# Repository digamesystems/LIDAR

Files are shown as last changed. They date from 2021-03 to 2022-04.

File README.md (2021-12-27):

## Title: 
Next-Generation systems for Park Data collection

### Authors: 
John Price, Jason Pitts, Bailee Allen, Jared Plunket

### Abstract: 

Recent advances in low power wireless technologies have enabled simple, high-speed connectivity to sensors used for gathering environmental data. Much of the currently deployed sensor infrastructure in the park system, however, is not designed to support wireless connectivity. As a result, park staff are required to visit each sensor site and make manual connections to devices to download data for applications like trail use monitoring. Sometimes these sensors are in areas with rugged terrain, adding to the difficulty in extracting the information and even increasing risk to the safety of park personelle. We propose to explore adding a low-power wireless link, (Bluetooth Low Energy, WiFi and LoRAWAN) to novel environmental sensors to allow ‘touchless’ access to this information. 

### Technical Approach: 
The need for accurate statistics around the use of our recreation areas has been well appreciated for some time:

“Every manager of a recreation site needs three essential statistics: man-hours of use, number of visits, and peak loads.” (James and Ripley,1963) [[1](https://github.com/digamesystems/LIDAR/blob/main/docs/Reference/rp_se003.pdf)]

In trail utilization applications, these statistics are often gathered by infrared detectors tied to a microprocessor-controlled counter with memory that logs the data as a function of time. One popular system of this type is made by TRAFX Research Ltd. [[2](https://www.trafx.net/about)]. We propose to add a combination of WiFi, Bluetooth and LoRaWAN connectivity to the system to enable ‘touchless’ downloading of information from the device’s memory when a researcher is near. 
 
Other applications include Vehicle Counting to better understand Park Visitation statistics.

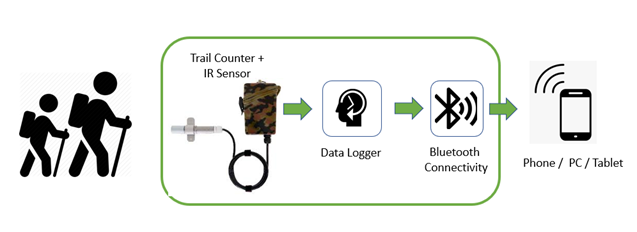
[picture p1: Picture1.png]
System Schematic


*Figure 1.* Proposed System

A working prototype will be developed to allow the exploration of: 
- Power and cost limitations for a next generation system
- Wireless performance under various conditions including range, connection speed and reliability
- New sensor technologies like LIDAR that might eliminate the drawbacks of current "On Road" sensor solutions
- Environmental requirements 
- User experience and UI design 
- Impact of ‘touchless’ downloads on system reliability
- How this capability might improve the quality of research data.
  
The project would also serve as a learning platform for the student intern community, offering opportunities in electrical, mechanical and software engineering.

### References: 
[[1](https://github.com/digamesystems/LIDAR/blob/main/docs/Reference/rp_se003.pdf)] - Instructions for Using Traffic Counters to Estimate Recreation Visits and Use George A. James; Thomas H. Ripley, Res. Pap. SE-3. Asheville, NC: U.S. Department of Agriculture, Forest Service, Southeastern Forest Experiment Station. 14 p. (1963).

[[2](https://www.trafx.net/about)] – TRAFX Research Ltd.

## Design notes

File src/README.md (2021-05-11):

## Title: 
Source files for Next-Generation Systems for Park Data collection

### Authors: 
John Price

### Abstract: 

Found herein are source files for the project, including the main application(s), and example programs that demonstrate how to work with the various sensors / modules we are using. 

* [SerialToSerialBT](https://github.com/digamesystems/LIDAR/tree/main/src/SerialToSerialBT) This example code is in the Public Domain (or CC0 licensed, at your option.) By Evandro Copercini - 2018. This example creates a bridge between Serial and Classical Bluetooth (SPP) and also demonstrate that SerialBT have the same functionalities of a normal Serial
* [esp32_bluetooth_tester](https://github.com/digamesystems/LIDAR/tree/main/src/esp32_bluetooth_tester) A little app to test Bluetooth connectivity range. Make a Bluetooth connection to the device "ShuttleCounter" with [Serial BlueTooth Terminal](https://play.google.com/store/apps/details?id=de.kai_morich.serial_bluetooth_terminal&hl=en_US&gl=US). The device will issue a count value every second. 
* [esp32_people_counter](https://github.com/digamesystems/LIDAR/tree/main/src/esp32_people_counter) A LIDAR-Based people counting system for shuttle buses.
* [esp32_tfminiplus_correlation_test](https://github.com/digamesystems/LIDAR/tree/main/src/esp32_tfminiplus_correlation_test) Testing algorithms that use correlation techniques for Vehicle Detection.
* [esp32_tfminiplus_example](https://github.com/digamesystems/LIDAR/tree/main/src/esp32_tfminiplus_example) A little program to show how to work with the TFMini-Plus LIDAR sensor.
* [esp32_ttminiplus_sd_ds3231](https://github.com/digamesystems/LIDAR/tree/main/src/esp32_ttminiplus_sd_ds3231) The HEIMDALL vehicle counting application.

`

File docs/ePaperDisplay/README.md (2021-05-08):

# ePaper Display Candidates

WaveShare 
* [1.54 Inch ePaper Display](https://www.waveshare.com/product/displays/e-paper/1.54inch-e-paper-module.htm)

Adafruit
* [1.54 Inch ePaper Display + SD Card](https://www.adafruit.com/product/4196)
* [Technical Details](https://learn.adafruit.com/adafruit-1-54-eink-display-breakouts)
* [Arduino Library](https://github.com/adafruit/Adafruit_EPD)

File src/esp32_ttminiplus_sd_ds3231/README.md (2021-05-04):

## esp32_tfminiplus_sd_ds3231.ino

### Description:
This application supports the Digame Systems HEIMDALL traffic counting system. 

### Authors: 
John Price

### System Components:
* [ESP32 WROOM 32D development board](https://docs.espressif.com/projects/esp-idf/en/latest/esp32/hw-reference/esp32/get-started-devkitc.html)
* One of several compatible LIDAR sensors (see below)
* A [micro SD card breakout module](https://www.adafruit.com/product/254) for system configuration settings and backup.
* A battery backed [real time clock module](https://www.adafruit.com/product/3013)
* [Solar panel](https://voltaicsystems.com/9-watt-panel/)
* Rechargable [battery pack](https://voltaicsystems.com/v50/)
* IP67 Rated Enclosure

### Overview:

At startup, program parameters are read from a configuration file, CONFIG.TXT found on the micro SD card. These may be changed by editing the file. File format is simple text contiaining the following parameters: 

    device name  -- User Defined
    distance threshold -- Less than this distance detected by the LIDAR sensor counts as vehicle 'presence' 
    operating mode (currently only opmodeThreshold and opmodeCorrelation are supported)
    SSID -- Network name
    password -- Network password
    serverURL -- Address for http POSTs of JSON messages

Once parameters are loaded, the device attempts to connect to the network with the specified credentials. If successful, system time is set from a connection to an NTP server and the real time clock is updated. In the event of a failure, the last known time set in the RTC will be used. The RTC is based on the DS3231 chip which has high accuracy and is temperature compensated. It should be accurate to within a few seconds a year without adjustment.

At this point, the main loop executes and the system makes repeated distance measurments using the LIDAR sensor over UART. Default acquisition rate is 100Hz and the distances measured are accurate to a few centimeters over ranges from 0.1 - 12 meters (under optimal conditions).

The software is compatible with several LIDAR sensors from the [Benewake](http://en.benewake.com/) "TF" family: 
* [TFMini-S](http://en.benewake.com/product/detail/5c345e26e5b3a844c472329c.html) 0-12 M Range
* [TFMini-Plus](http://en.benewake.com/product/detail/5c345cd0e5b3a844c472329b.html) 0-12 M Range, IP67
* [TF-Luna](http://en.benewake.com/product/detail/5e1c1fd04d839408076b6255.html) 0-8 M Range, Low Cost
* [TF-03](http://en.benewake.com/product/detail/5c345cc2e5b3a844c472329a.html) 0-180 M Range!, IP67

Passing vehicles generate a characteristic signature as they travel through the beam which is interpreted by the software. -- Several algorithms for detection are under evaluation including threshold-based and correlation-based approaches.

On the detection of a vehicle, a JSON message is created for delivery to the server URL specified in the configuration. JSON messages are of the following format: 

    "{"deviceName": "YourDeviceName",
      "deviceMAC":  "YourMACAddress",
      "timeStamp":" "YourRTCTime (UTC)",
      "eventType":  "<boot|heartbeat|vehicle>"
      }"
      
For "vehicle" events, an optional array of raw LIDAR data maybe included in the payload:
   
    <...pseudo code snippet...>
    
    jsonPayload = jsonPayload + "operatingMode": "<opmodeThreshold|opmodeCorrelation>,"
    jsonPayload = jsonPayload + "rawData": + "["
    using index_t = decltype(buffer)::index_t;
    for (index_t i = 0; i < buffer.size(); i++) {
        jsonPayload = jsonPayload + buffer[i]; 
        if (i<buffer.size()-1){ 
          jsonPayload = jsonPayload + ",";
        }
    }
    //Close out the message
    jsonPayload = jsonPayload + "]}";
          
This allows us to analyze the last second or so of raw data before the sensor claimed that a car had passed.

An attempt is then made to send the data to the server. If this fails, data is saved to the SD card until a successful connection can be reestablished. Reconnect attempts are made every 5 minutes by default. Once a successful connection has been made, the data saved locally is sent to the server and upon completion, the data stored on the SD card is deleted.

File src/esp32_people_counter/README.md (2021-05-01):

## esp32_people_counter

### Description: 

A LIDAR-based sensor system for detecting people boarding and unboarding shuttle buses. Events are reported via Bluetooth Classic to a networked tablet that relays the information to a server. 

### Authors: 
John Price, Bailee Allen, Jared Plunket

### System Components:
* [ESP32 WROOM 32D development board](https://docs.espressif.com/projects/esp-idf/en/latest/esp32/hw-reference/esp32/get-started-devkitc.html)
* One of several compatible LIDAR sensors (see below)
* [Enclosure](https://www.polycase.com/dc-45f)

### JSON Bluetooth Payload:

The Sensor reports 'people' events over Bluetooth in JSON format. Examples:`

    {"deviceName":"Bailee's Office","deviceMAC":"60:3a:6a:2a:3:a8","eventType":"person","count":"1"}
    {"deviceName":"Bailee's Office","deviceMAC":"60:3a:6a:2a:3:a8","eventType":"person","count":"2"}
    {"deviceName":"Bailee's Office","deviceMAC":"60:3a:6a:2a:3:a8","eventType":"person","count":"3"}
    {"deviceName":"Bailee's Office","deviceMAC":"60:3a:6a:2a:3:a8","eventType":"person","count":"4"}

### Sensors:
The software is compatible with several LIDAR sensors from the [Benewake](http://en.benewake.com/) "TF" family: 
* [TFMini-S](http://en.benewake.com/product/detail/5c345e26e5b3a844c472329c.html) 0-12 M Range
* [TFMini-Plus](http://en.benewake.com/product/detail/5c345cd0e5b3a844c472329b.html) 0-12 M Range, IP67
* [TF-Luna](http://en.benewake.com/product/detail/5e1c1fd04d839408076b6255.html) 0-8 M Range, Low Cost
* [TF-03](http://en.benewake.com/product/detail/5c345cc2e5b3a844c472329a.html) 0-180 M Range!, IP67

### Testing the Sensor: 
* https://youtu.be/LPxUawpHUEk
* https://youtu.be/7mM1T-jgChU
* https://youtu.be/dQw4w9WgXcQ

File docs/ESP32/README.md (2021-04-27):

https://github.com/espressif/esp-idf/blob/cf457d4/docs/en/hw-reference/esp32/get-started-devkitc.rst

Pinout Reference Guide:
https://randomnerdtutorials.com/esp32-pinout-reference-gpios/

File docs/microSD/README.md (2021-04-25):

Adafruit microSD card breakout module:

https://github.com/adafruit/MicroSD-breakout-board

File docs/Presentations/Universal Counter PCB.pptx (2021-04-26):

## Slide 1

Counter Board Concept

eInk Display*

UI

Indicators / LEDs *

ESP32-WROOM-32D Dev Board

Micro SD Card Breakout *

LoRaWAN *

Wireless

WiFi

Battery-Backed Real Time Clock *

Peripherals

TFMini-Plus LIDAR Sensor Connector x2

Bluetooth / BLE

Temperature / Humidity Sensor *

Power: 5-12VDC, USB, Solar Panel

*Optional

## Counter Board Concept

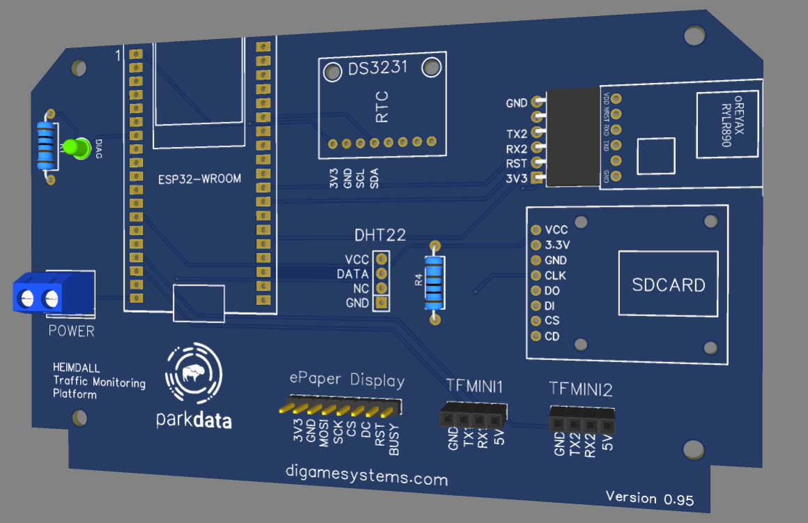
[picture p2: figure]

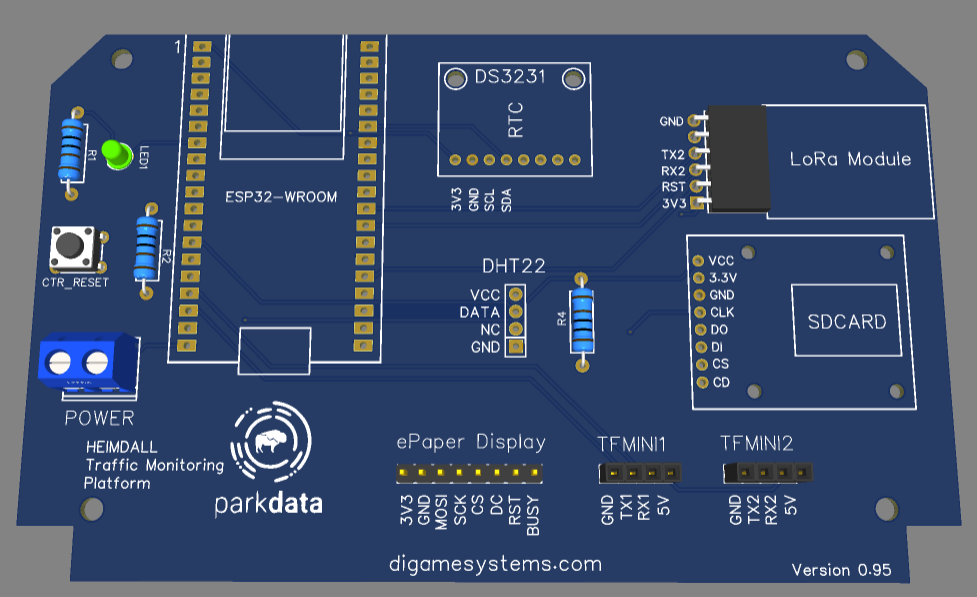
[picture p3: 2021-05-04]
images/Universal Counter PCB Concept/PCB_095_3D.png

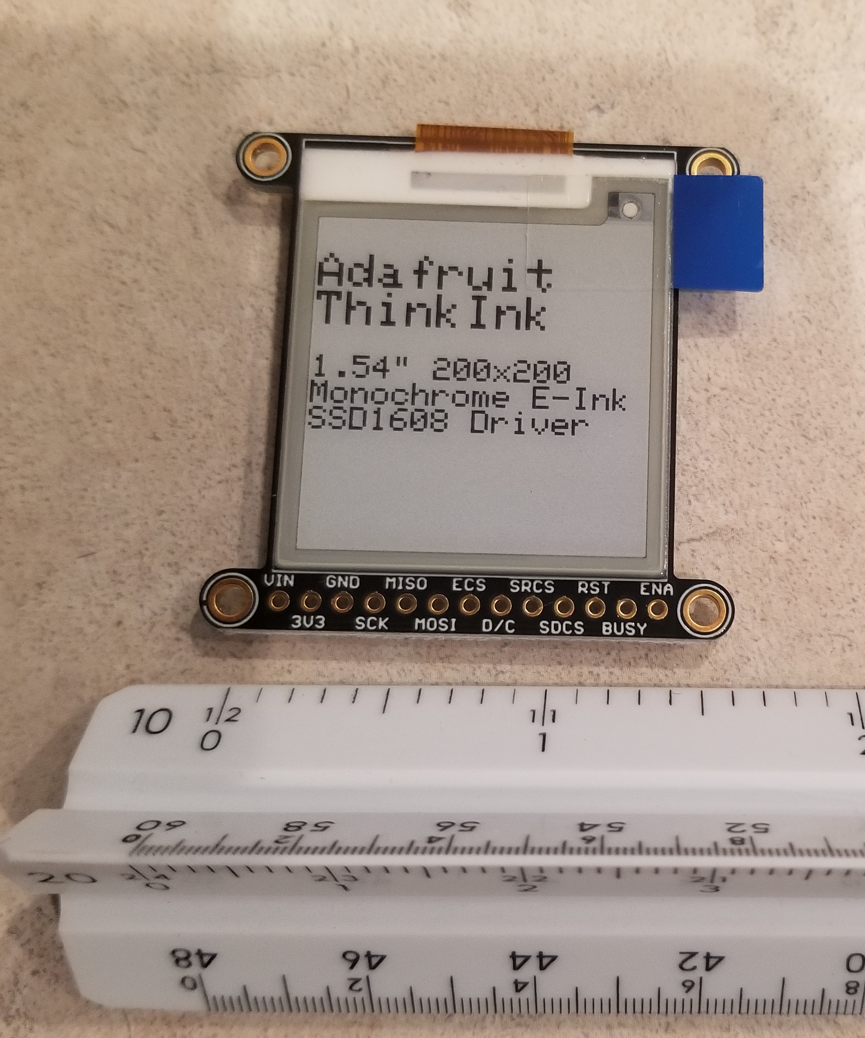
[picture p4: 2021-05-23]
docs/ePaperDisplay/Adafruit 1.54 inch ePape Display/adafruit1_54_eInk.jpg

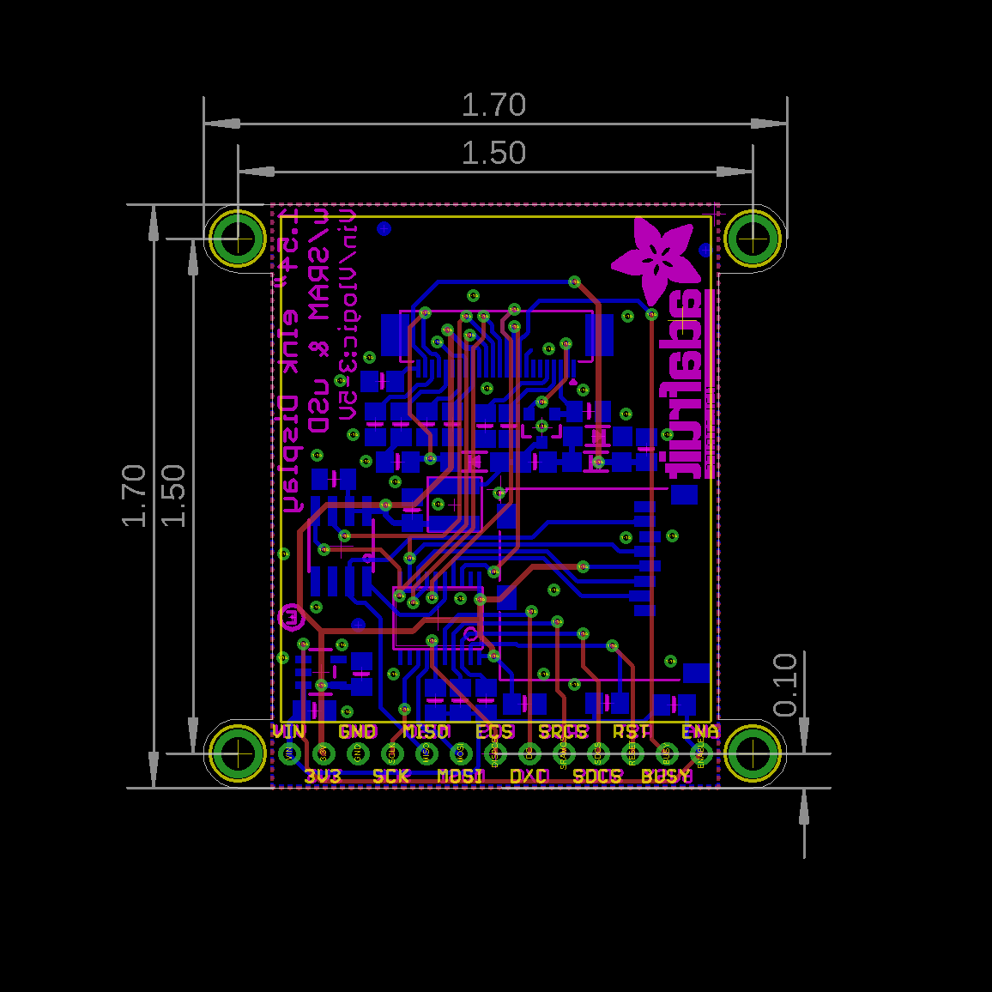
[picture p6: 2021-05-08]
docs/ePaperDisplay/WaveShare 1.54 inch ePaper Display/adafruit_1_54_e_ink_display.png

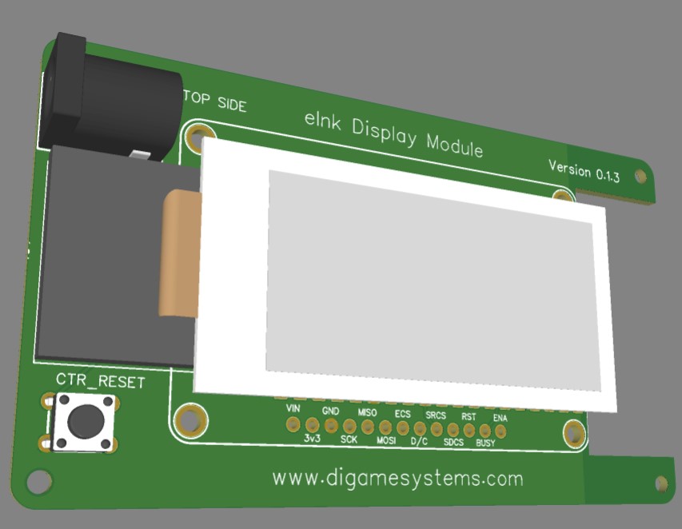
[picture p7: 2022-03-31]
images/Shuttle Counter Pics/Screenshot 2022-03-04 084442.jpg

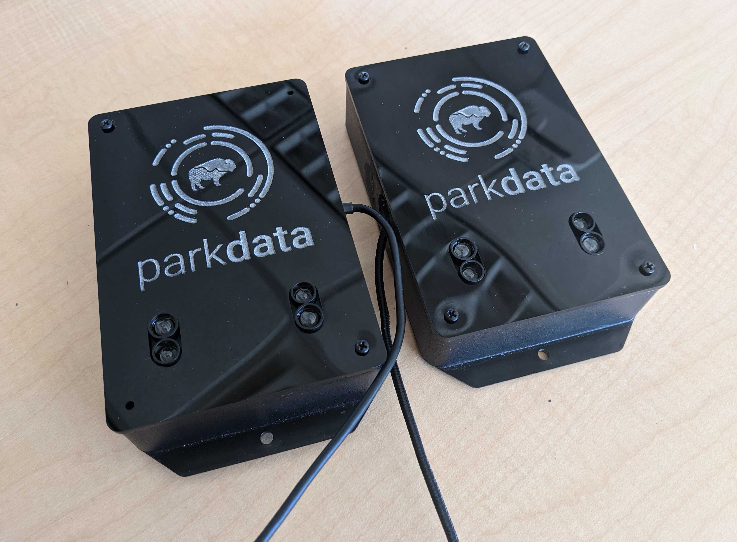
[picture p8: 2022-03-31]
images/Heimdall Pics/PXL_20211220_215736145.MP.jpg

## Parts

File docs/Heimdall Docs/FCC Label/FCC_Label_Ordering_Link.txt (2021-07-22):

https://www.onlinelabels.com/products/ol223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

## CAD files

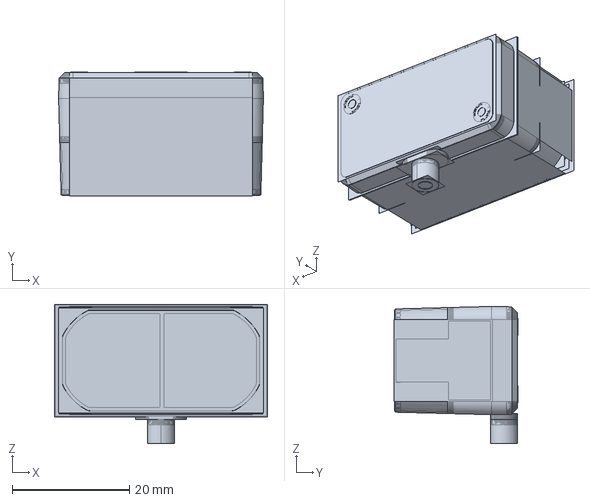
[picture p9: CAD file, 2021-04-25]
docs/LIDAR/TFMini-Plus/TFmini Plus 3D structure model.igs
36.4 x 21.2 x 23.8 mm

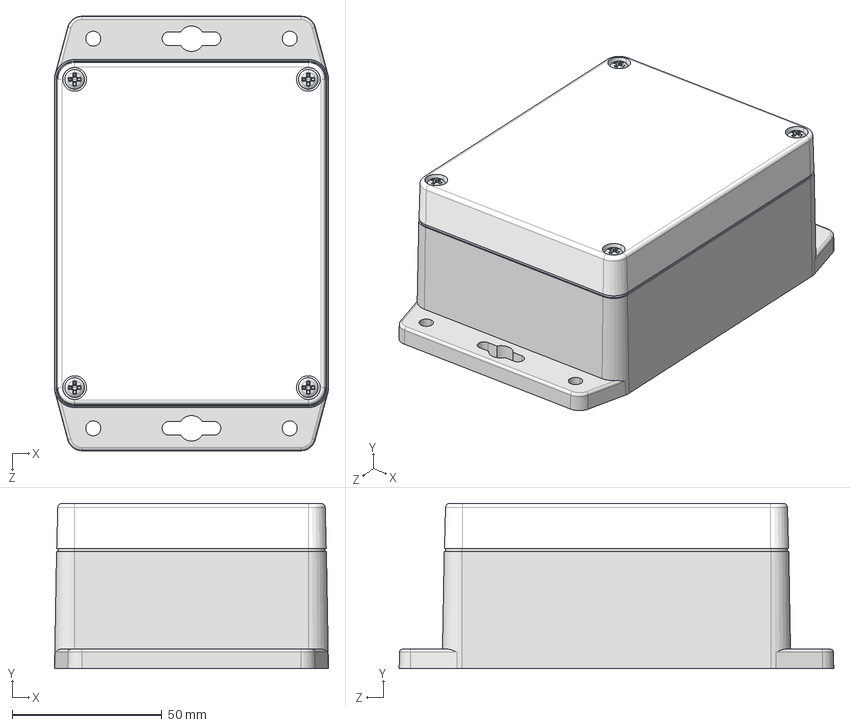
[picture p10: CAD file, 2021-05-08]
docs/Polycase/WC-23F/WC-23F.STEP
91.4 x 55.1 x 144.9 mm
W_-23BF_WP-23BF*15
W_-23C_WC-23C*08
SCREWS-SSM4-20_SCREWS-SSM4-20 x 4
W_-23BF-PCB_WP-23BF*15-PCB

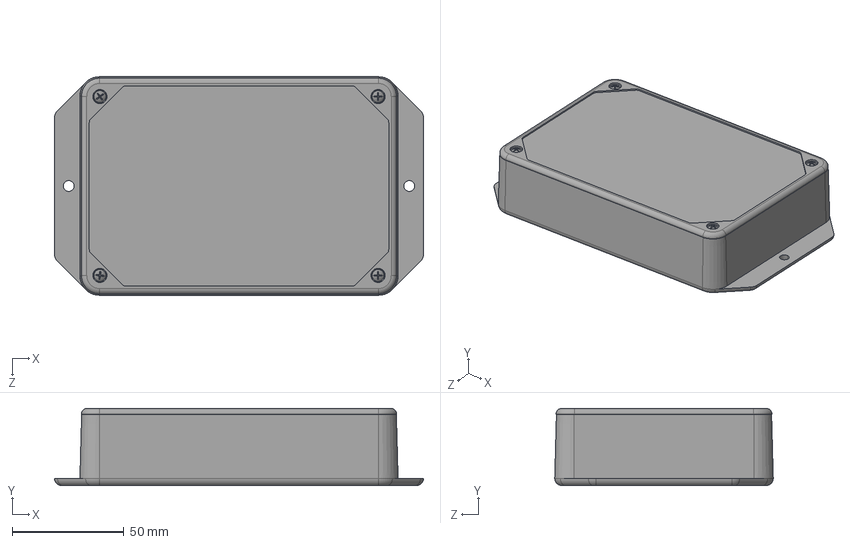
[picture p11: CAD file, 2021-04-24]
docs/Polycase/LP-61/LP-61FMBR_ASS'Y.STEP
165.1 x 34.5 x 97.8 mm
SCREWS-LP-BR_SCREWS-LP-BR x 4
LP-61B_LP-61BFMB
LP-61C_LP-61C-R

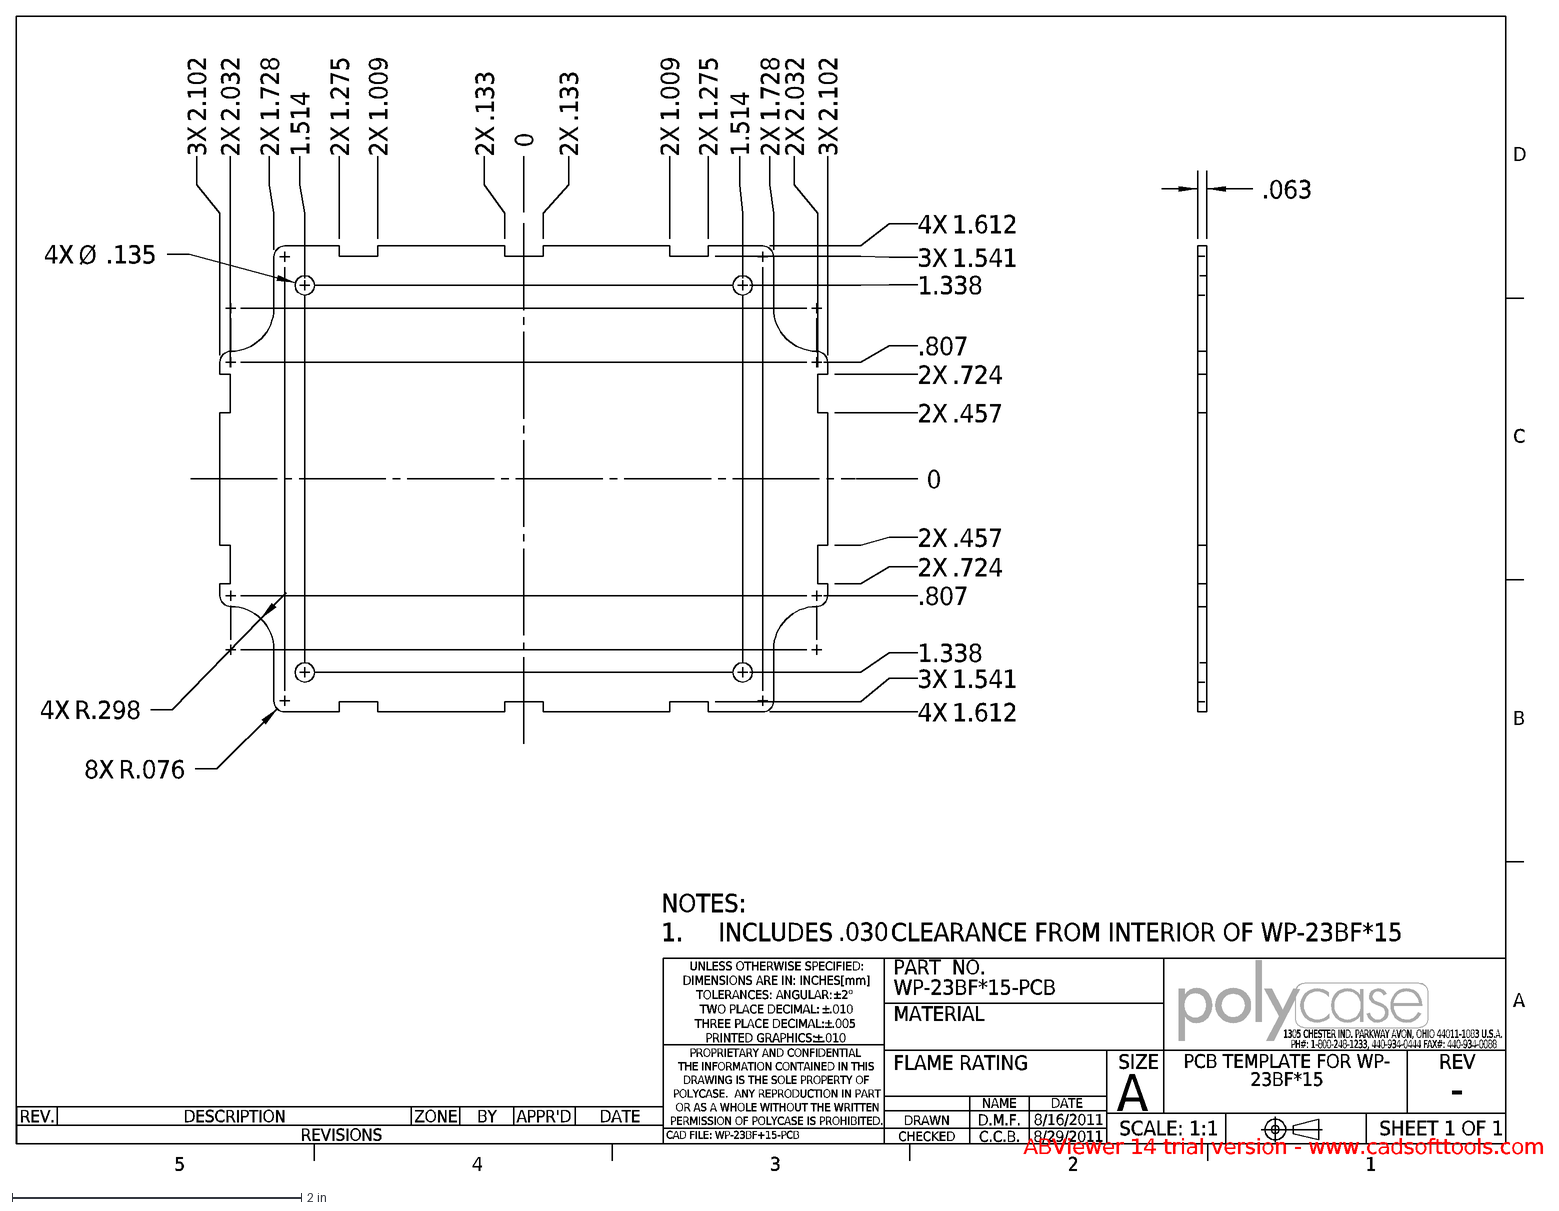
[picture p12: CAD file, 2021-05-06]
docs/Polycase/WC-23F/WP-23BF+15-PCB.dxf
1305 CHESTER IND. PARKWAY AVON, OHIO 44011-1083 U.S.A.
PH#: 1-800-248-1233, 440-934-0444 FAX#: 440-934-0088
NOTES:
INCLUDES
.030
CLEARANCE FROM INTERIOR OF WP-23BF*15
1.
1
A
B
C
D
2
3
4
5
SHEET 1 OF 1
SCALE: 1:1
REV
PART NO.
SIZE
PROPRIETARY AND CONFIDENTIAL
THE INFORMATION CONTAINED IN THIS
DRAWING IS THE SOLE PROPERTY OF
POLYCASE. ANY REPRODUCTION IN PART
OR AS A WHOLE WITHOUT THE WRITTEN
PERMISSION OF POLYCASE IS PROHIBITED.
PCB TEMPLATE FOR WP-
23BF*15
C.C.B.
D.M.F.
CHECKED
DRAWN
NAME
DATE
8/16/2011
8/29/2011
MATERIAL
FLAME RATING
-
CAD FILE: WP-23BF+15-PCB
UNLESS OTHERWISE SPECIFIED:
DIMENSIONS ARE IN: INCHES[mm]
TOLERANCES: ANGULAR:
±
°
TWO PLACE DECIMAL:
.010
THREE PLACE DECIMAL:
.005
PRINTED GRAPHICS:
WP-23BF*15-PCB
REV.
DESCRIPTION
ZONE
BY
APPR'D
REVISIONS
0
1.514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

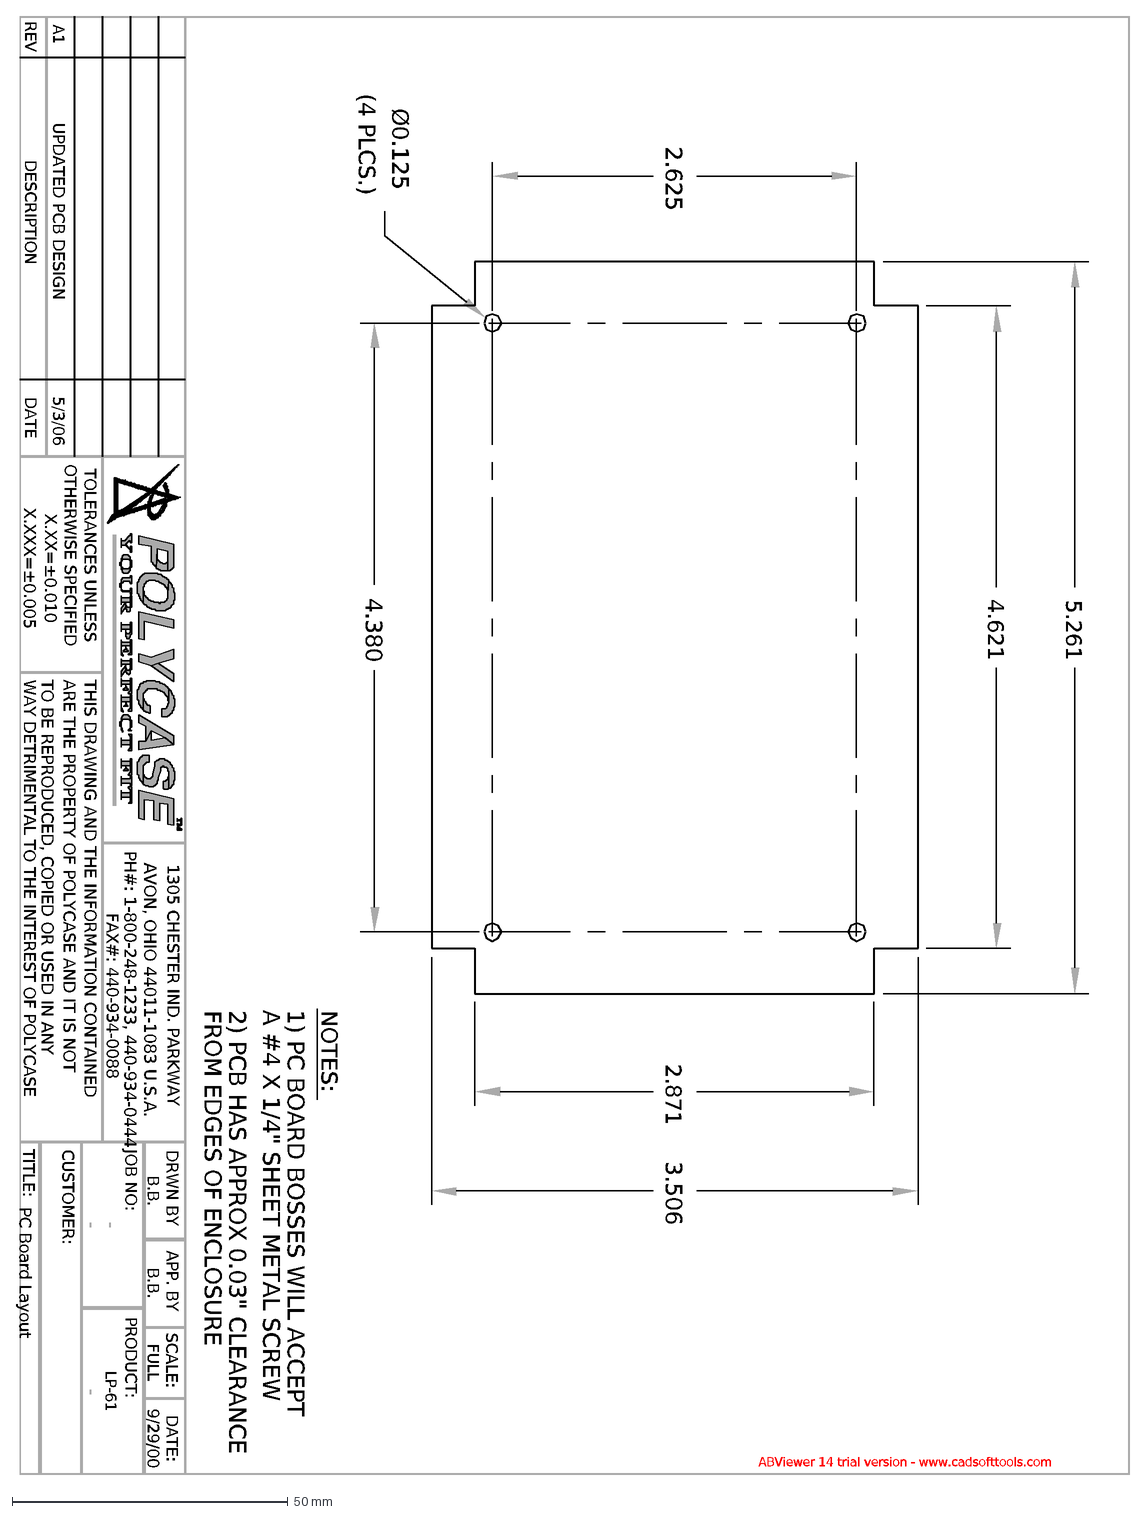
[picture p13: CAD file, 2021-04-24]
docs/Polycase/LP-61/PCB template PDF 7.dxf
REV
DESCRIPTION
DATE
OTHERWISE SPECIFIED
WAY DETRIMENTAL TO THE INTEREST OF POLYCASE
ARE THE PROPERTY OF POLYCASE AND IT IS NOT
THIS DRAWING AND THE INFORMATION CONTAINED
AVON, OHIO 44011-1083 U.S.A.
PH#: 1-800-248-1233, 440-934-0444
1305 CHESTER IND. PARKWAY
TO BE REPRODUCED, COPIED OR USED IN ANY
X.XXX=±0.005
TOLERANCES UNLESS
X.XX=±0.010
FAX#: 440-934-0088
DATE:
TITLE:
APP. BY
CUSTOMER:
JOB NO:
DRWN BY
PRODUCT:
SCALE:
B.B.
FULL
9/29/00
LP-61
PC Board Layout
NOTES:
1) PC BOARD BOSSES WILL ACCEPT
A #4 X 1/4" SHEET METAL SCREW
2) PCB HAS APPROX 0.03" CLEARANCE
FROM EDGES OF ENCLOSURE
2.871
3.506
4.621
5.261
2.625
4.380
Ø0.125
(4 PLCS.)
A1
UPDATED PCB DESIGN
5/3/06
ABViewer 14 trial version - www.cadsofttools.com

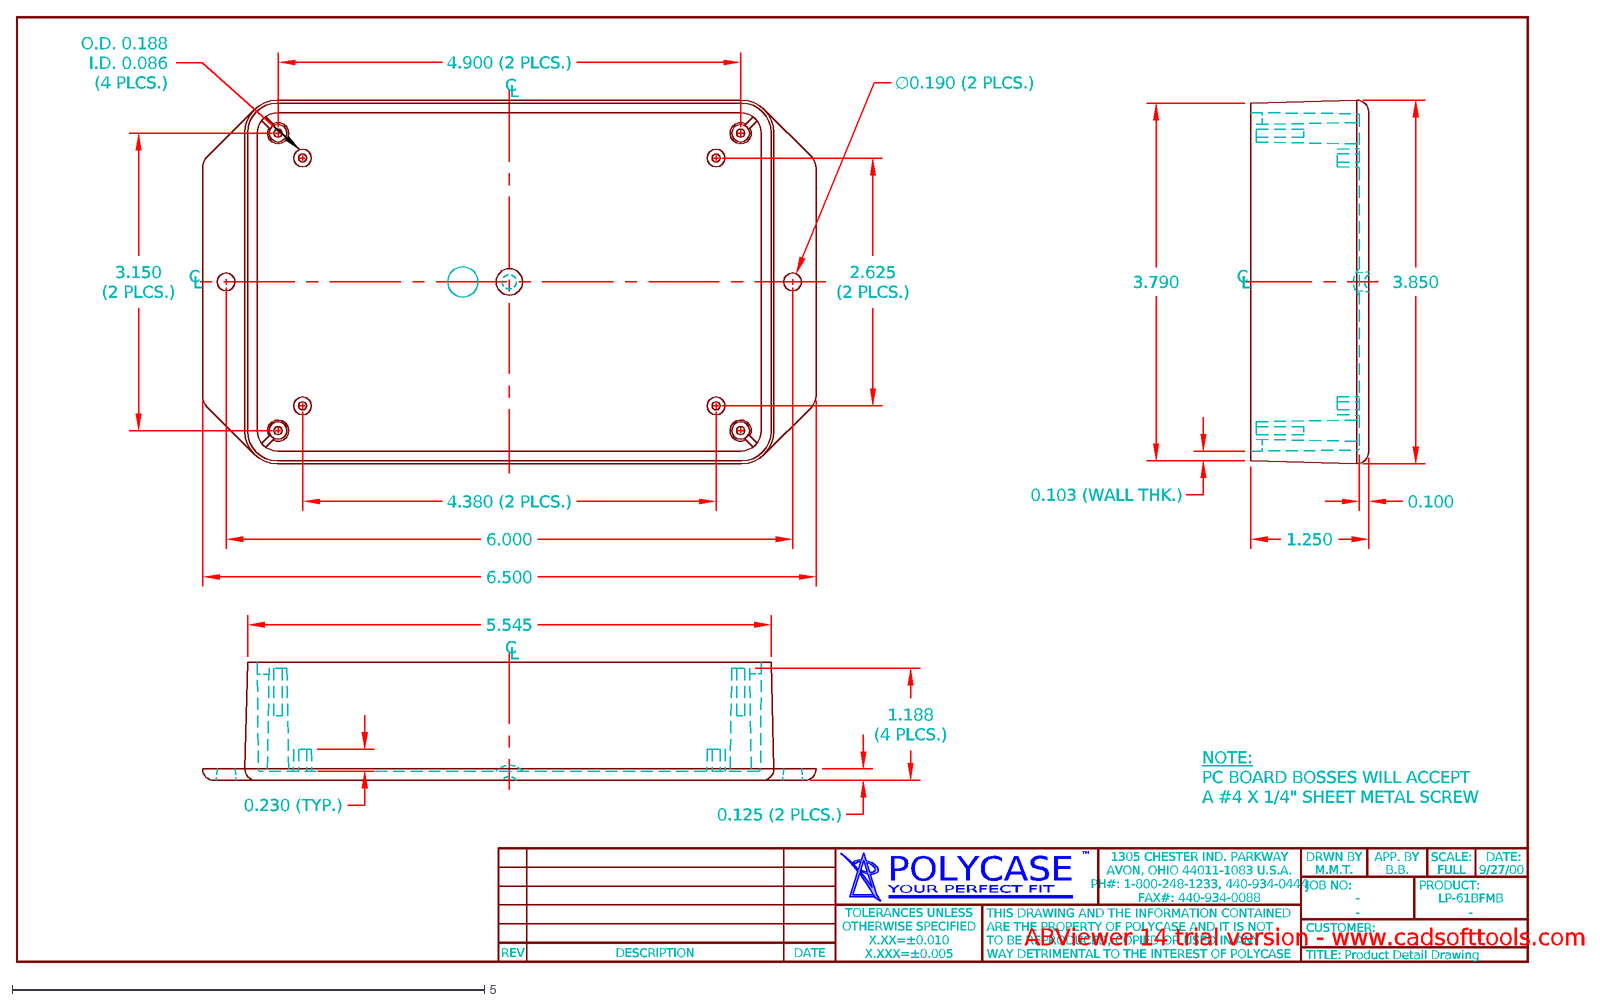
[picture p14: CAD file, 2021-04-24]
docs/Polycase/LP-61/LP-61BFMB.dxf
DESCRIPTION
REV
DATE
M.M.T.
B.B.
FULL
9/27/00
-
LP-61BFMB
Product Detail Drawing
POLYCASE
YOUR PERFECT FIT
TM
OTHERWISE SPECIFIED
WAY DETRIMENTAL TO THE INTEREST OF POLYCASE
ARE THE PROPERTY OF POLYCASE AND IT IS NOT
THIS DRAWING AND THE INFORMATION CONTAINED
AVON, OHIO 44011-1083 U.S.A.
PH#: 1-800-248-1233, 440-934-0444
1305 CHESTER IND. PARKWAY
TO BE REPRODUCED, COPIED OR USED IN ANY
X.XXX=±0.005
TOLERANCES UNLESS
X.XX=±0.010
FAX#: 440-934-0088
DATE:
TITLE:
APP. BY
CUSTOMER:
JOB NO:
DRWN BY
PRODUCT:
SCALE:
C
L
4.380 (2 PLCS.)
6.000
6.500
4.900 (2 PLCS.)
3.150 (2 PLCS.)
2.625 (2 PLCS.)
O.D. 0.188 I.D. 0.086 (4 PLCS.)
3.850
3.790
0.103 (WALL THK.)
0.100
1.250
5.545
0.230 (TYP.)
0.125 (2 PLCS.)
1.188 (4 PLCS.)
NOTE: PC BOARD BOSSES WILL ACCEPT A #4 X 1/4" SHEET METAL SCREW
∅0.190 (2 PLCS.)
ABViewer 14 trial version - www.cadsofttools.com

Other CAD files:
docs/Polycase/LP-61/LP-61PCB.dwg
docs/Polycase/WC-36/WP-36BF+15.DWG
docs/Polycase/WC-36/WC-36C+08.DWG
docs/Polycase/WC-23F/WP-23BF+15.DWG
docs/Polycase/WC-36/WP-36B+15-PCB.dxf
docs/Polycase/LP-61/LP-61C-R.dwg
docs/Polycase/WC-23F/WC-23F+1508.DWG
docs/Polycase/WC-36/WC-36F+1508.DWG
docs/Polycase/WC-23F/WC-23C+08.DWG
docs/Polycase/LP-61/LP-61FXXT_ASS'Y.STEP
docs/Polycase/LP-61/LP-61FXXR_ASS'Y.STEP
docs/Polycase/LP-61/LP-61FMBT_ASS'Y.STEP
docs/LIDAR/TFMini-Plus/tfmini_plus.blend
docs/Polycase/LP-61/LP-61BFMB.dwg
docs/Polycase/LP-61/LP-61C-T.dwg
docs/Polycase/WC-23F/WP-23BF+15-PCB.DWG
docs/Polycase/WC-36/WP-36B+15-PCB.DWG
docs/Solar Panel and Battery/solar panel and battery.blend
docs/ePaperDisplay/WaveShare 1.54 inch ePaper Display/1_54inch_display.blend
docs/microSD/Micro_SD_Breakout.blend

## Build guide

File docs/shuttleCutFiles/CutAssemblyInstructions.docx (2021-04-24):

Sensor Enclosure Cut Files

Shuttle LIDAR Sensor | AXIS Communications case

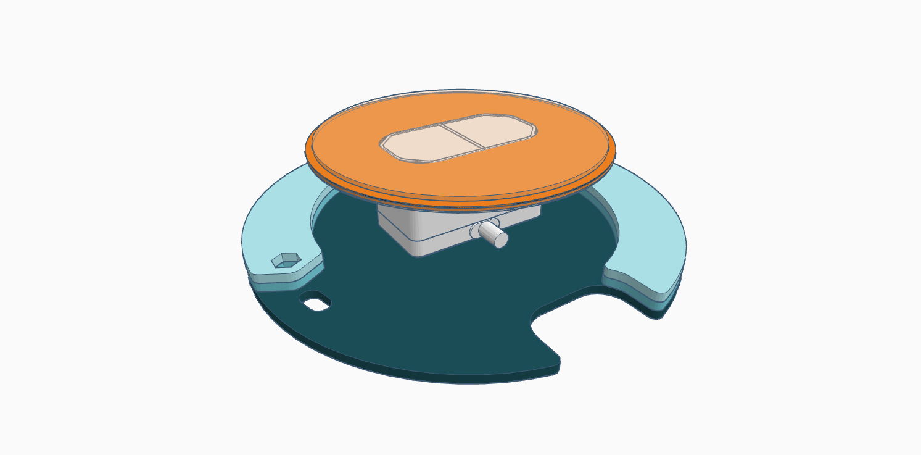
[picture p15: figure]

TO CUT:

Wood Base (Blue)

Material: ⅛ inch wood

Power Settings: Dependent on cutter

Files:

shuttleSensorBase.svg

shuttleSensorSpacers.svg

Acrylic Covers (Orange)

Material: 2mm Clear Acrylic

Power Settings: Dependent on cutter

Files:

shuttleSensorInnerCover.svg

shuttleSensorOuterCover.svg

Note:

Be sure to cover your acrylic with masking tape or use pre-masked acrylic sheeting to avoid scorch marks and heat patterns on the finished product.

TO ASSEMBLE:

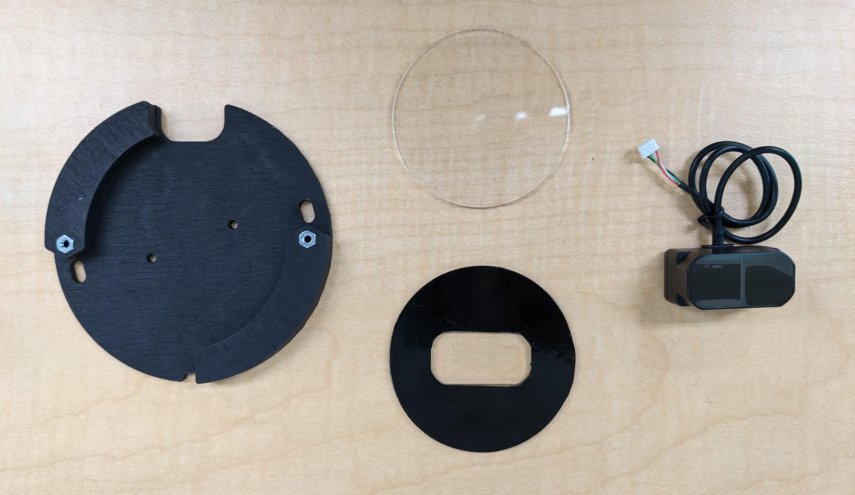
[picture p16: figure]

Materials:

Loctite or wood glue

M3-.50 Hex Nuts (2)

Black Vinyl Sticker

TF-Mini Plus LIDAR Sensor

Double Sided Sticky Tape

Instructions:

Cut black vinyl to fit inner acrylic piece and attach (shuttleSensorInnverCover.svg)

DO NOT LASER CUT VINYL.

Glue wood spacers together and attach to the wood base, lining up the perimeters as shown above.

Paint wood black if desired and insert hex nuts. Use tabletop or another solid surface to push them in until they are flush with the wood.

Insert clear acrylic cover into the top of the AXIS camera case and snap in black acrylic piece behind it to secure it.

Place the TF-mini plus sensor inside the indentation and screw the wooden base into place.

Note:

Use double sided sticky tape or other low-profile adhesive to keep the sensor in place if additional security is needed. Screwing into place is not necessary.

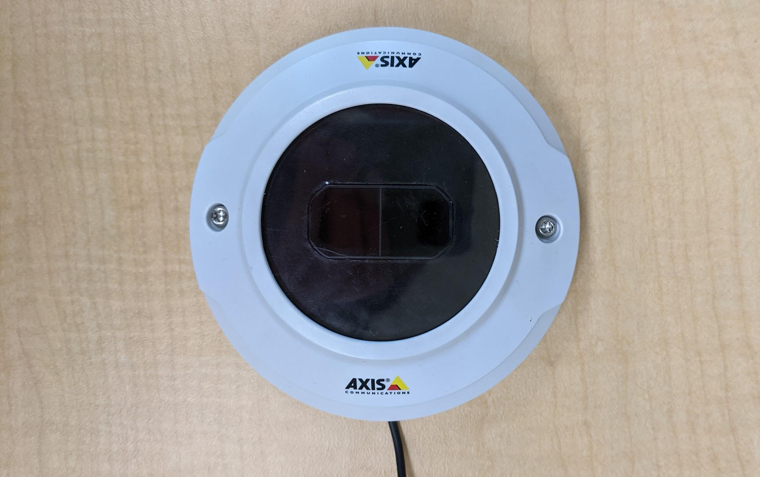
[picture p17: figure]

Finished product

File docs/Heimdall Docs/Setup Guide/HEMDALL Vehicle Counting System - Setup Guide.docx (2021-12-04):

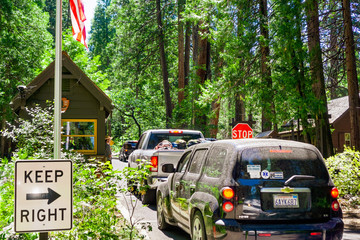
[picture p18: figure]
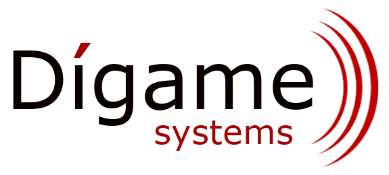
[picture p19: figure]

| HEMDALL VCS (Vehicle Counting System) Setup Guide Dígame Systems 88 E. San Fernando St. Suite 1511 San Jose, CA 95113

Trademarks

Dígame is a trademark of Dígame Sytems. Microsoft, Windows, and Windows NT are registered trademarks of Microsoft Corporation. Other brand and product names are registered trademarks or trademarks of their respective holders.

Statement of Conditions

In the interest of improving internal design, operational function, and/or reliability, Dígame reserves the right to make changes to the products described in this document without notice. Dígame does not assume any liability that may occur due to the use or application of the product(s) or circuit layout(s) described herein.

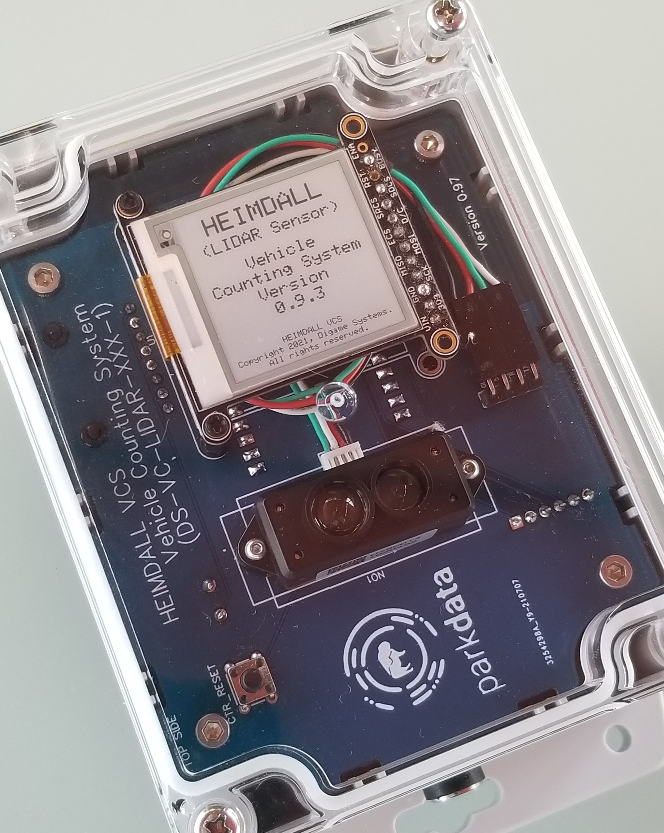
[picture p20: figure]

# Introduction

Thank you for your purchase!

The HEIMDALL VCS is an easy-to-deploy, state-of-the-art vehicle tracking system that provides fast, reliable traffic data for your application.

TODO: -- Put a blub here describing the collaboration between Dígame and the Parkdata project.

Unlike other vehicle counting technologies like loop sensors that require cutting up the roadway, HEIMDALL VCS is deployed roadside and never touches the road surface. This not only makes installation simple but saves on maintenance costs and reduces traffic disruptions.

The key is the sensing technology – LIDAR. The same technology used in some self-driving cars.

Vehicle counting sensors are deployed roadside and use an invisible laser to measure the distance from the sensor to any object in front of it up to 100 times per second. When a vehicle passes in front of the sensor, a characteristic “signature” is generated that the sensor uses to determine that a traffic event has occurred.

Vehicle events are transmitted wirelessly using a long-range RF link (LoRa) to a network base station that forwards the information to the Parkdata cloud service.

After a quick initial configuration, all of this happens automatically. Count events simply show up in the Parkdata dashboard.

Let’s get started.

# System Components

HEIMDAL VCS consists of several components that work together to feed data to the Parkdata system.

- A Solar Power System: Traffic Counters are powered by a rechargeable lithium-ion battery pack which is maintained by a 10 Watt solar panel. Both the panel and battery packs are weatherproof and designed to be mounted outdoors, near the sensor.
- One or more LIDAR Vehicle Counters: Vehicle counters are typically mounted on a post roadside pointing across traffic. The LIDAR sensor is placed at a height of about one meter above the road’s surface so the laser can easily detect most vehicles. Detection parameters for the LIDAR “signature” algorithm may be easily adjusted at setup using a cell phone.
- One or more LoRa / WiFi Base Stations: Base station units are designed to collect data from multiple Vehicle Counters and forward events to the Parkdata system over your WiFi network. The base station and the counters communicate using a long-range wireless protocol (LoRa) with a line-of-sight range of over a kilometer. – The reliable range of the system is a function of both environmental factors (hills, trees, walls, etc.) and LoRa transmission parameters. These parameters can be adjusted through the base station’s web user interface.

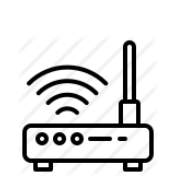
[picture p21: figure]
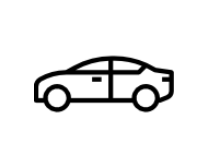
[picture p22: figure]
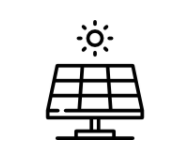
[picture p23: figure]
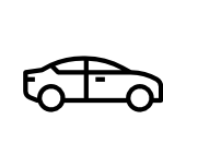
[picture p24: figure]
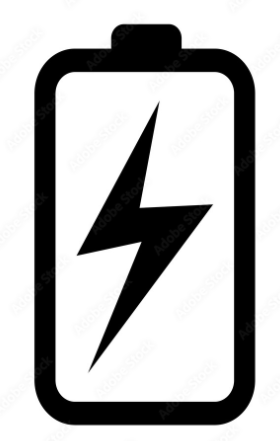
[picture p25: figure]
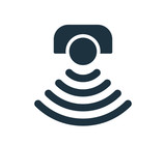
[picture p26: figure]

Block Diagram:

LoRa

Parkdata

WiFi

LIDAR

Solar

Base

Station

# Setting up the System

## Hardware

For our two-counter system, in the box you should find:

- Two (2) Vehicle Counters with LIDAR sensor and eInk display.
- Two (2) Battery Pack modules.
- One (1) Base Station unit with eInk display.
- Two (2) Voltaic Systems 10-Watt Solar Panels. (https://voltaicsystems.com/10-watt-panel-etfe/)
- Two (2) Solar Panel Mounting Brackets. (https://voltaicsystems.com/bracket/)
- Two (2) Waterproof solar panel extension cables/adapters for the battery packs.
- Two (2) 3’ DC power cables to power the counters when the battery pack needs to be placed some distance from the counter.
- Two (2) 1.5’ DC power cables to power the counters when the battery pack can be mounted closer to the counter.
- One (1) USB to DC power cable to power the base station.
- One (1) USB to waterproof connector for charging the battery pack on USB.
- One (1) USB power plug to power the base station.

### TODO: Detailed setup pictures of connectors / mounting, solar panels, battery packs. – Instructions on ‘gotchas’ we find.

South

1 Meter

### Notes

Solar panels should be mounted to face South to achieve the best efficiency throughout the day.

Connect the battery packs to the solar panels using the extension / adapter cable with the blue waterproof connector.

The fit of the black connector to the solar panel cable is tight. You should feel a click when the two are properly engaged.

The blue end screws into the corresponding connector on the battery pack. – There is a white alignment mark on both connectors. Tighten the connector in place to finger tightness to achieve a watertight seal.

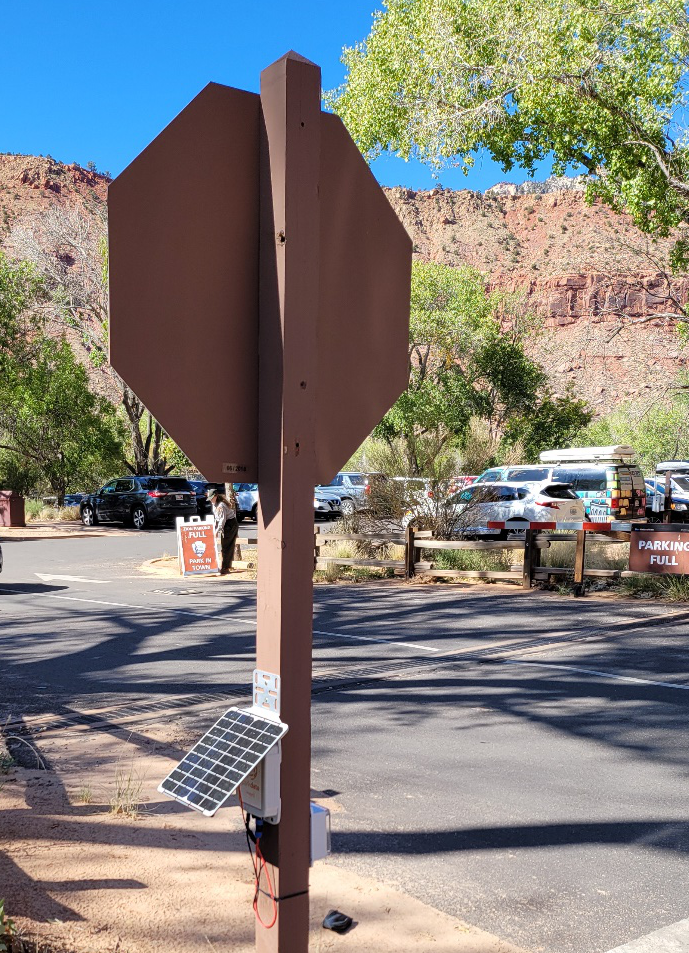
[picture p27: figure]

Battery packs should be mounted with the connections facing down and mounted in the shade of the solar panel, if possible.

The Vehicle Counters should be mounted to point across the flow of traffic near the side of the roadway with the power connector pointing down. The black, LIDAR sensor should be mounted at a height of about 1 meter above the road surface.

The default threshold for detection is 3 meters from the sensor. If the installation requires the sensor be placed farther than this from where the vehicles pass, this parameter can be adjusted. (See below)

The base station unit should be placed indoors, preferably near a window within range of your WiFi router. The higher the base station can be placed, the better. (Ground effects can negatively influence range.) If possible, orient the base station unit vertically, so the orientation of the base station matches that of the counters.

## Software / Firmware

When working with the Vehicle Counters and the Base Stations, it is important to understand the difference between two modes wireless devices can support: Access Point Mode and Station Mode.

- Station Mode: Is what a laptop computer, a printer or our Base Station units normally use. In this mode, the device connects to the local wireless router and the router provides internet access. To make the connection, the device needs to know the SSID and Password for the local network.

How do we load these parameters into the Base Station for a new installation? This is where Access Point Mode comes in.

- Access Point (AP) Mode: In Access Point Mode, a device acts like a tiny router and creates its own wireless LAN to which other devices can connect. (There is no access to the greater Internet in this mode.) Both the Vehicle Counters and Base Station units can be put into Access Point Mode by holding down the CTR_RST button on the board during the boot process. Counters can be brought up in AP mode simply by holding your hand <20 cm from the LIDAR sensor on power up. – An un-configured Base Station unit will come up in AP mode by default.

When the devices come up in AP mode, they display their SSID and IP address on the eInk display and start up a small web server for configuration.

### AP Mode Configuration

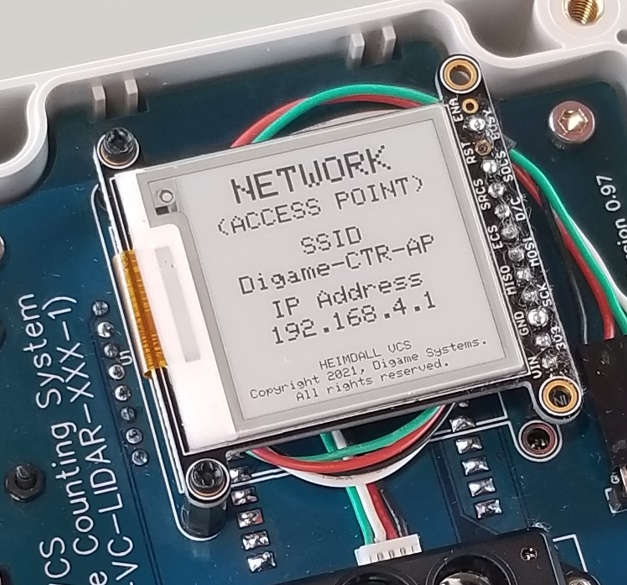
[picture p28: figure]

When the Base Station or Vehicle Counter is booted into AP Mode the eInk display will look something like this:

SSIDs:

Base Station Dígame -STN-AP

Counter Dígame -CTR-AP

The default IP address for a unit running in AP mode is : 192.168.4.1

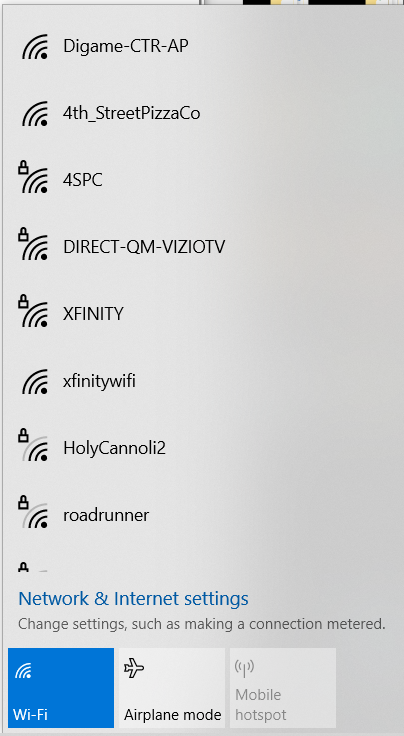
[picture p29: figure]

Open your network settings on either your laptop or phone and click on the SSID to connect.

You may get a message that the internet is unavailable. – This is normal. AP Mode is a strictly local network.

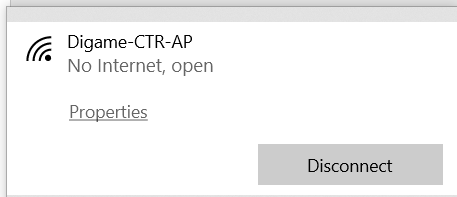
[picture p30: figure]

### The Web User Interface

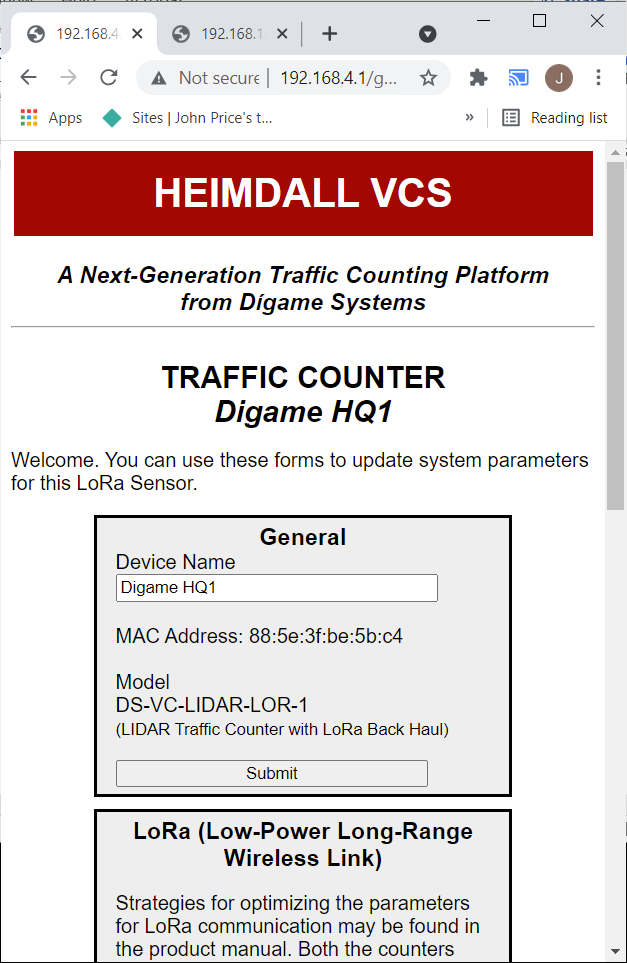
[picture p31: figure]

From your browser, now navigate to the IP address shown on the eInk display. (192.168.4.1) You will be presented with a simple device configuration interface.

Changes made here will be saved to device memory and applied on the next boot.

Parameters are described below.

### General

Both Vehicle Counters and Base Stations have a section that allows you to set the device name and inspect the device’s MAC address and Model Number.

### LoRa

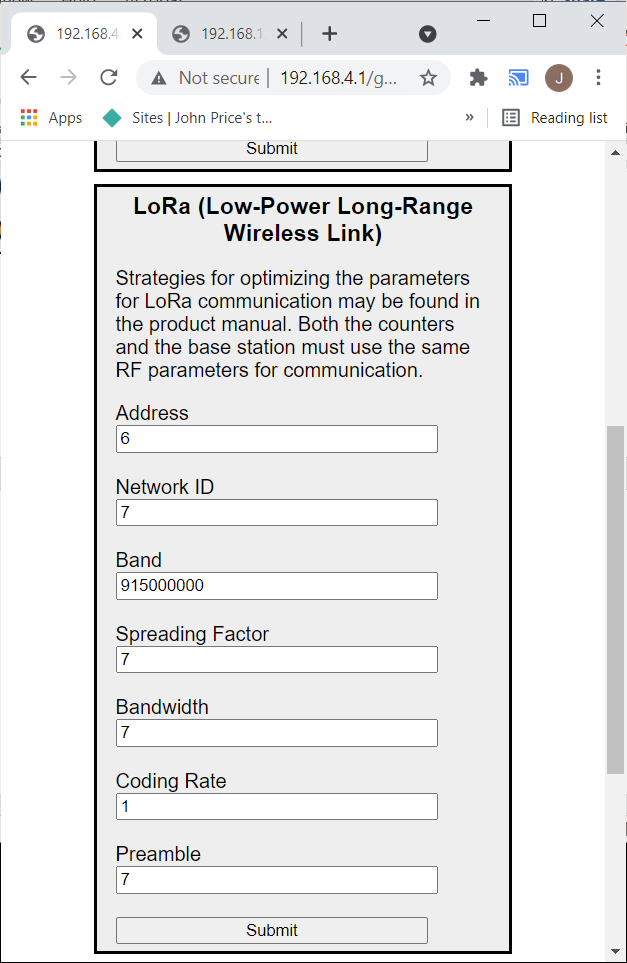
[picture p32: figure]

The LoRa radio link requires that the base station and vehicle counters both have the same settings for key RF parameters.

These settings can be changed to optimize link reliability and data throughput, but they must be the same on each end of the RF link. In most cases, the default settings should work well and the only thing that might need to be changed for a counter is its Address field.

Address: Base Stations are given the address of 1. It is recommended that all counters be given a unique address so that the base station can distinguish between them. Address 0 is a special address that broadcasts to all listeners.

Network ID: Devices can only communicate with each other if they have the same Network ID. This allows multiple base stations to work in the same area.

Spreading Factor: A parameter related to the time it takes to transmit data and the range the data can be sent reliably. Larger spreading factors take longer to send but can send information over longer distances. Smaller spreading factors transmit data more quickly, but less reliably. Valid range is 7-12.

Bandwidth: Related to how quickly bits are transmitted for a given Spreading Factor. The default value of 7 (125 kHz) should be sufficient for most applications.

Band: The frequency (in Hz) of the RF transmissions. In cases where there is single frequency interference, this may be changed.

Coding Rate: Smaller values result in faster transmission.

Preamble: A series of transitions at the start of a message that helps the radios synchronize. Higher values are more reliable but take longer to transmit. (Should rarely need to be changed.)

### LIDAR Parameters

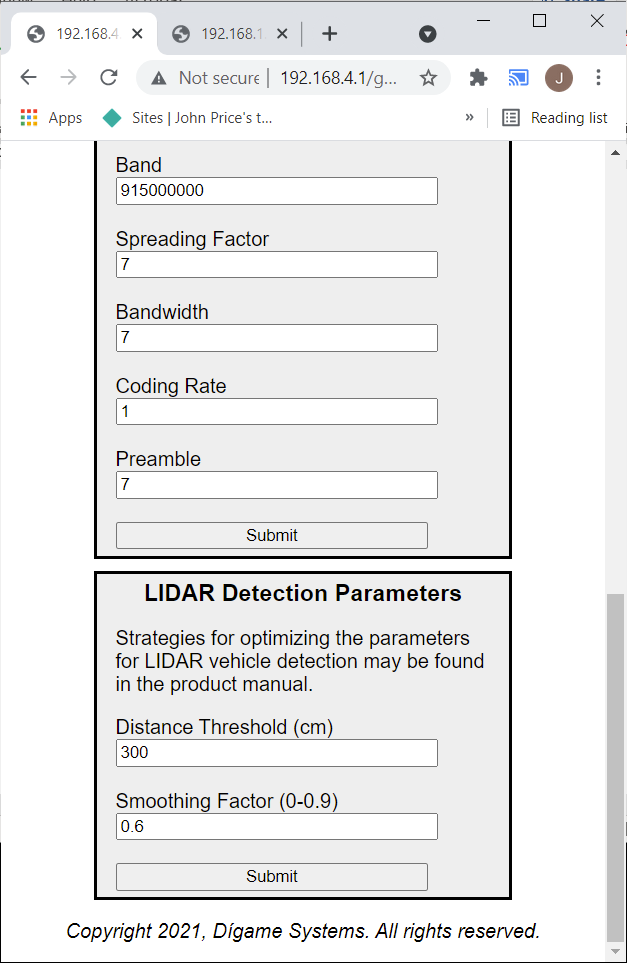
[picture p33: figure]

For Vehicle Counters, two parameters can be tuned to optimize performance.

Distance Threshold (cm): If the LIDAR sensor detects an object inside this distance, it will count as “present”. Once the object moves beyond this threshold (or leaves the area) the logic transitions to “absent”

An “absent” to “present” to “absent” sequence counts as a vehicle event and is reported to the system.

This parameter can be adjusted from the default value of 3 meters if a lane is especially wide.

Smoothing Factor: LIDAR data can be collected at speeds of up to 100 measurements per second. This term provides the option to adjust the amount of averaging that is done on the raw data to smooth out spurious noise coming from complex structures on a target.

Larger smoothing factors can slow system response and can lead to missing fast moving vehicles. Adjust this parameter with caution.

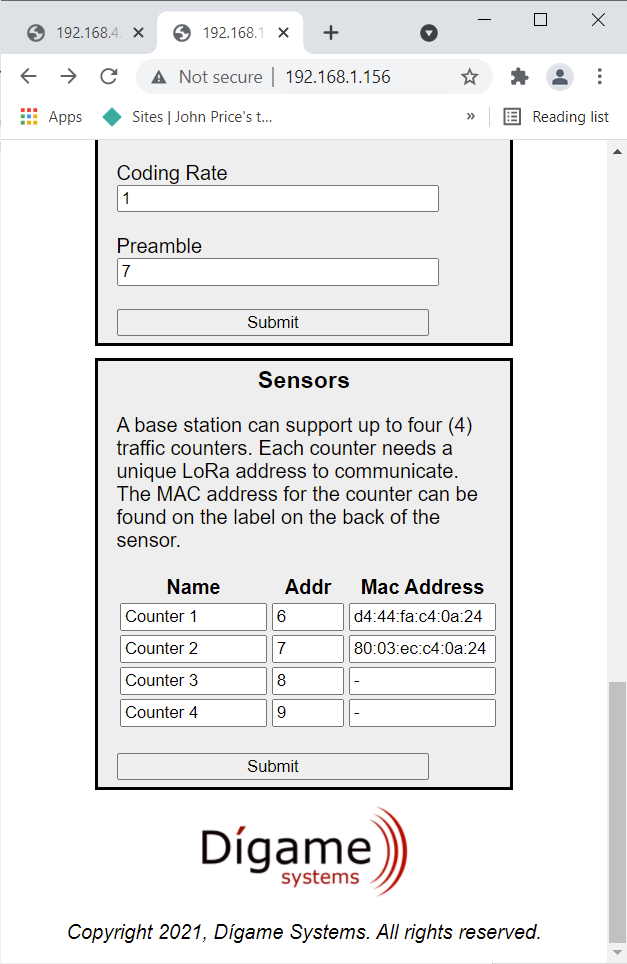
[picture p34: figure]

### Sensors

A Base Station can route data from multiple Vehicle Counters. (Current firmware supports 4.)

When a message comes in from a Counter, the device address is used to look up the sensor name and MAC address to be reported to the Parkdata system.

When configuring a new system, first note the MAC addresses and LoRa address for the counter (it is on a label on the back of the counters) and then enter them into the configuration interface on the Base Station.

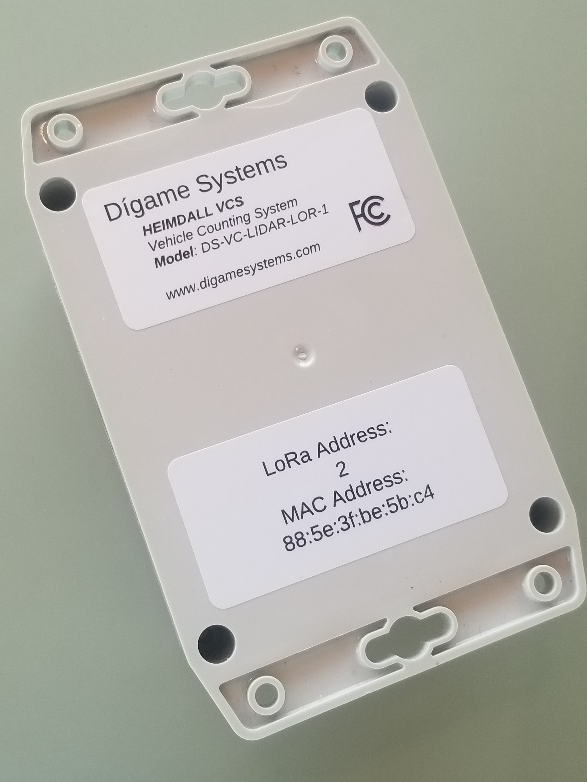
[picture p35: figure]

Counters broadcasting with addresses unknown to the base station will not be reported.

## Operation / Maintenance

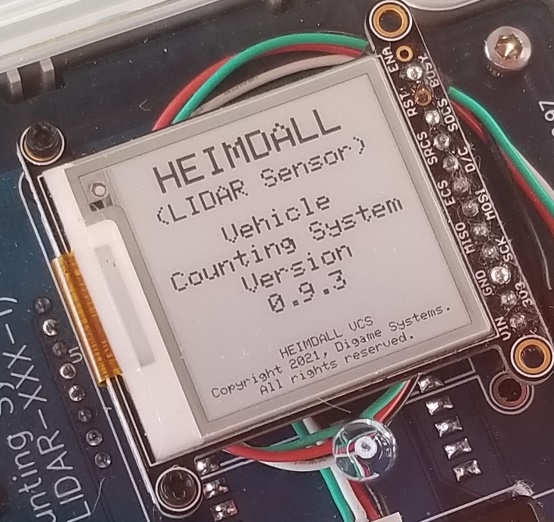
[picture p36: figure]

On power up, both the Counters and the Base Station will cycle through a series of screens, starting with a ‘splash’ screen that shows the current firmware version running on the device.

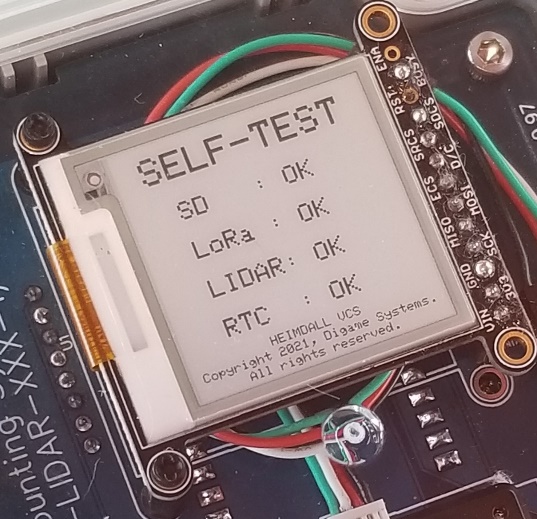
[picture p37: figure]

For Counters, the device will execute a series of Self-Test functions to verify the operation of the hardware.

If successful, a second screen will appear, indicating each system is functioning properly.

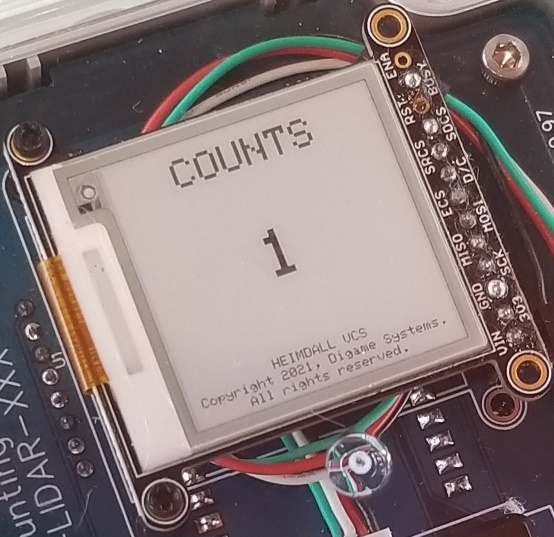
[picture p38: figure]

After the self-test, the Counter will issue a ‘boot’ message over the LoRa link, telling the Base Station that it has started, activate the LIDAR module, and begin looking for Vehicles. A screen showing the total number of counts since the system was booted is shown that is dynamically updated in real time.

This screen is especially useful during setup to verify correct operation.

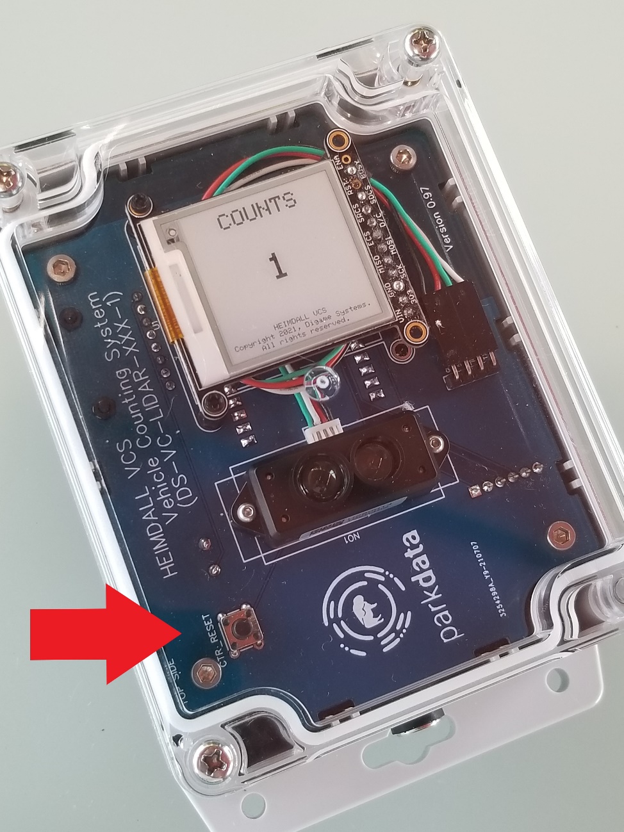
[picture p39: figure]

After setup, the total count can be reset to zero by pressing the button on the PCB labeled “CTR_RESET”.

### TODO: Add screens for Base Station Unit and describe Show a typical setup in an office environment?

### Maybe a picture of typical range observed for the default conditions?

## Troubleshooting

TBD

## Regulatory

FCC Statement:

This device complies with part 15 of the FCC Rules.

Operation is subject to the following two conditions: (1) This device may not cause harmful interference, and (2) this device must accept any interference received, including interference that may cause undesired operation.

NOTE: This equipment has been tested and found to comply with the limits for a Class B digital device, pursuant to part 15 of the FCC Rules.

These limits are designed to provide reasonable protection against harmful interference in a residential installation. This equipment generates, uses and can radiate radio frequency energy and, if not installed and used in accordance with the instructions, may cause harmful interference to radio communications. However, there is no guarantee that interference will not occur in a particular installation. If this equipment does cause harmful interference to radio or television reception, which can be determined by turning the equipment off and on, the user is encouraged to try to correct the interference by one or more of the following measures:

- Reorient or relocate the receiving antenna.
- Increase the separation between the equipment and receiver.
- Connect the equipment into an outlet on a circuit different from that to which the receiver is connected.
- Consult the dealer or an experienced radio/TV technician for help.

Changes or modifications not expressly approved by the party responsible for compliance could void the user’s authority to operate the equipment.

This unit contains:

FCC ID QLYRYLR896

FCC ID 2AC7Z-ESPWROOM32.

Appendix A - Technical Specifications

Use Case

• Vehicle counting applications: 1-2 Lanes of traffic.

• Vehicle speed: up to 60 MPH

LIDAR Sensor Specifications

• Operating Range: 0.1 – 12 meters

• Accuracy: +/- 5 cm

• Field of View: 3.6 degrees

• Frame Rate: 100 Hz

• Counting Accuracy: >99% counting accuracy at distances < 10 meters and speeds < 60 mph. (Performance may vary in extreme weather conditions.)

Interface / Communications

• WiFi, LoRaWan (with accessory gateway)

• Cellular service: Not included.

• Security: HTTPs, WPA under WiFI

• API: JSON-based for easy integration

Mounting / Power

• Mounting: Surface mount or pole mount (custom options available)

• Input Voltage: 5-7 VDC (DC power supply or supplied solar panel output)

• Power Consumption: < 0.5 Watts typ.

• Battery: Capacity 12,800mAh, 47 Watt Hours

• Battery Type: Li-Ion

• Protection: Short circuit over charge, over discharge, over temperature (45°Input Cutoff, 60° Output Cutoff), under temperature (0° Input Cutoff, -20° Output Cutoff)

Environmental

• Enclosure: High Impact UV resistant polycarbonate, IP67/NEMA4.

• Operational Temperature: -20℃ to +45℃

• Storage Temperature: -20°C to +60°C

• Warranty: Replacement, 3 years parts and labor.

Appendix B - Related Documents

TBD

Page | 1Copyright 2021, Dígame Systems. All Rights Reserved.DS-DCN-00012-A

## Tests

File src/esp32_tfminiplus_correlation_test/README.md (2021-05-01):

## esp32_tfminiplus_correlation_test

### Description: 

Exploring Correlation methods for LIDAR vehicle detection

### Authors: 
John Price

### System Components:
* [ESP32 WROOM 32D development board](https://docs.espressif.com/projects/esp-idf/en/latest/esp32/hw-reference/esp32/get-started-devkitc.html)
* [TFMini-S](http://en.benewake.com/product/detail/5c345e26e5b3a844c472329c.html) 0-12 M Range

### Testing the Sensor: 
* [Looking at Cross Correlation](https://youtu.be/juIM_V4DJ_s)

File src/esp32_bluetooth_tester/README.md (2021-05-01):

## esp32_bluetooth_tester.ino

### Description:
A little app to test Bluetooth range. Issues a counter value at 1 second intervals. Connect to "ShuttleCounter" and move around to check connectivity. 

### Authors: 
John Price

### System Components:
* [ESP32 WROOM 32D development board](https://docs.espressif.com/projects/esp-idf/en/latest/esp32/hw-reference/esp32/get-started-devkitc.html)

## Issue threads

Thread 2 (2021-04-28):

TFMini-Plus Gives Spurious Counts when it is Raining

digamesystems, 2021-04-28:
**Describe the bug**
In our vehicle counting application, the TFMini-Plus LIDAR is giving spurious results when it rains. Extra counts appear in the data stream, presumably from reflections off of rain drops...

**To Reproduce**
Steps to reproduce the behavior:
1. Run the vehicle counter when it is raining.
2. Compare actual v reported number of vehicle events.
3. Be sad.

**Expected behavior**
Ignore the rain.

**Screenshots**
If applicable, add screenshots to help explain your problem.

**Desktop (please complete the following information):**
 - OS: [e.g. iOS]
 - Browser [e.g. chrome, safari]
 - Version [e.g. 22]

**Smartphone (please complete the following information):**
 - Device: [e.g. iPhone6]
 - OS: [e.g. iOS8.1]
 - Browser [e.g. stock browser, safari]
 - Version [e.g. 22]

**Additional context**
Add any other context about the problem here.

digamesystems, 2022-01-12:
As of 0.9.65c, changes have been made that greatly reject the influence of rain and snow.

Closing.

Closed 2022-01-12.

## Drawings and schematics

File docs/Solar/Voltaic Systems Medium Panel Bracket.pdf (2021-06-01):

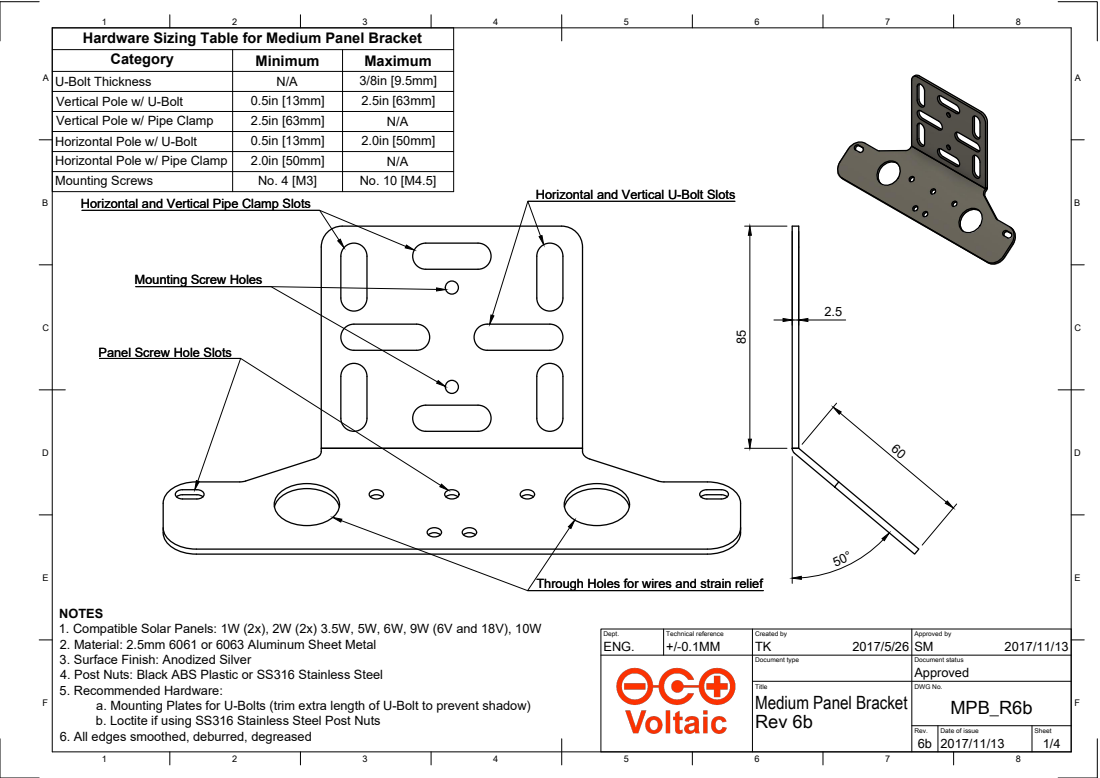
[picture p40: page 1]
Horizontal and Vertical Pipe Clamp Slots; Horizontal and Vertical U-Bolt Slots

Hardware Sizing Table for Medium Panel Bracket
Category | Minimum | Maximum

U-Bolt Thickness | N/A | 3/8in [9.5mm]
Vertical Pole w/ U-Bolt | 0.5in [13mm] | 2.5in [63mm]
Vertical Pole w/ Pipe Clamp | 2.5in [63mm] | N/A
Horizontal Pole w/ U-Bolt | 0.5in [13mm] | 2.0in [50mm]
Horizontal Pole w/ Pipe Clamp | 2.0in [50mm] | N/A
Mounting Screws | No. 4 [M3] | No. 10 [M4.5]

Horizontal and Vertical U-Bolt Slots Horizontal and Vertical Pipe Clamp Slots

Mounting Screw Holes

Panel Screw Hole Slots

Through Holes for wires and strain relief

NOTES
1. Compatible Solar Panels: 1W (2x), 2W (2x) 3.5W, 5W, 6W, 9W (6V and 18V), 10W
2. Material: 2.5mm 6061 or 6063 Aluminum Sheet Metal
3. Surface Finish: Anodized Silver
4. Post Nuts: Black ABS Plastic or SS316 Stainless Steel
5. Recommended Hardware:

Dept. ENG. | Technical reference +/-0.1MM | Created by TK 2017/5/26 | Approved by SM 2017/11/13

Document type | Document status Approved

Title Medium Panel Bracket Rev 6b | DWG No. MPB_R6b

a. Mounting Plates for U-Bolts (trim extra length of U-Bolt to prevent shadow)
b. Loctite if using SS316 Stainless Steel Post Nuts

6. All edges smoothed, deburred, degreased

Rev. 6b | Date of issue 2017/11/13 | Sheet

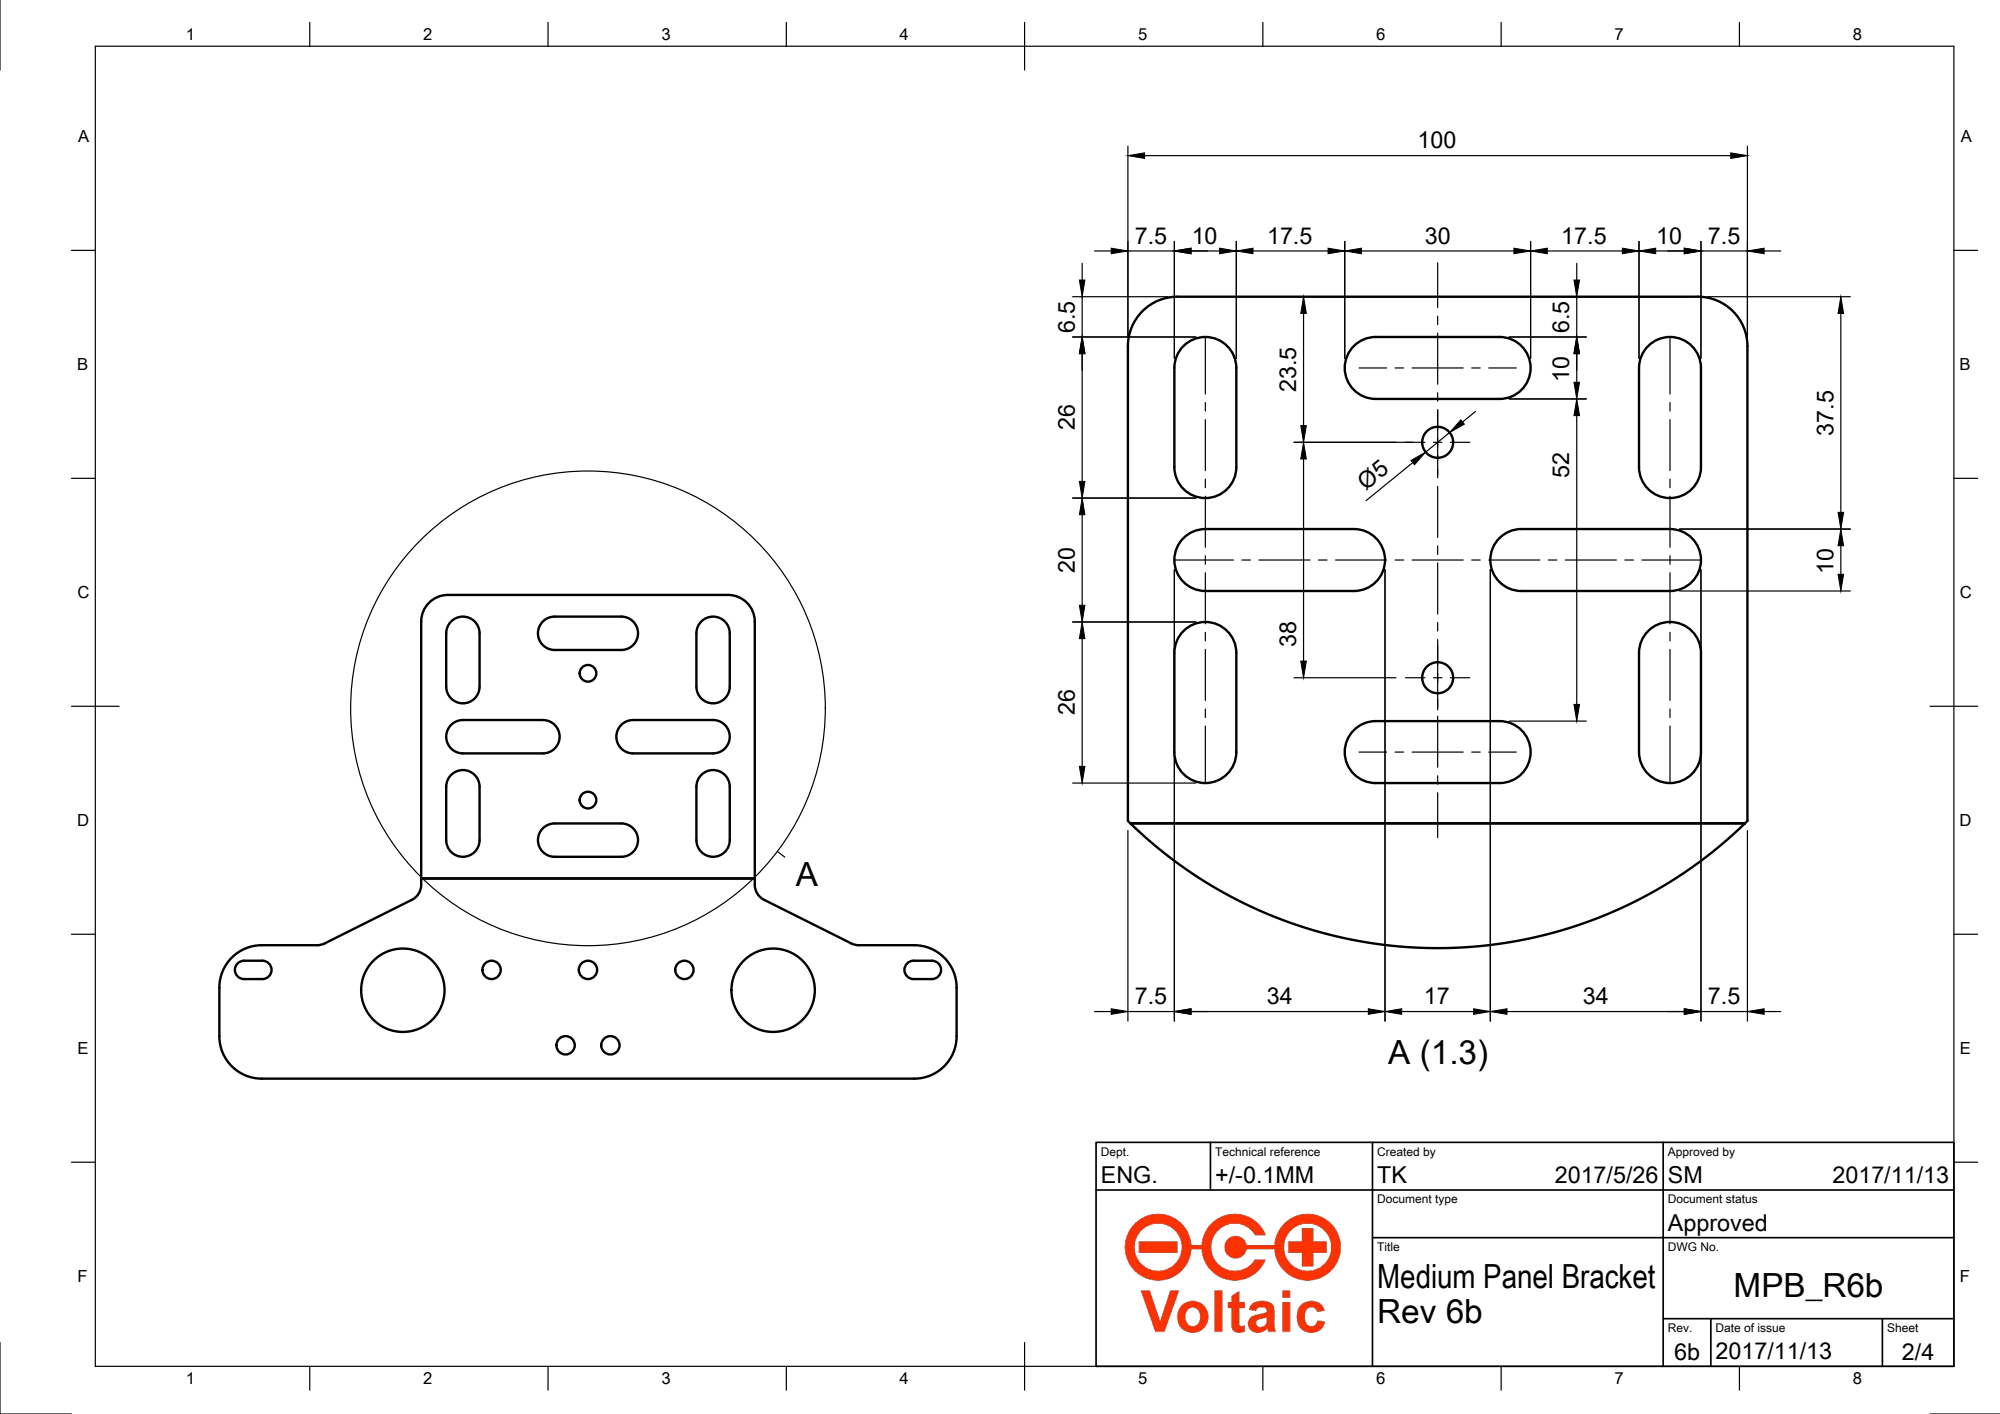
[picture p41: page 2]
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

Document type | Document status Approved

Title Medium Panel Bracket | DWG No. MPB_R6b

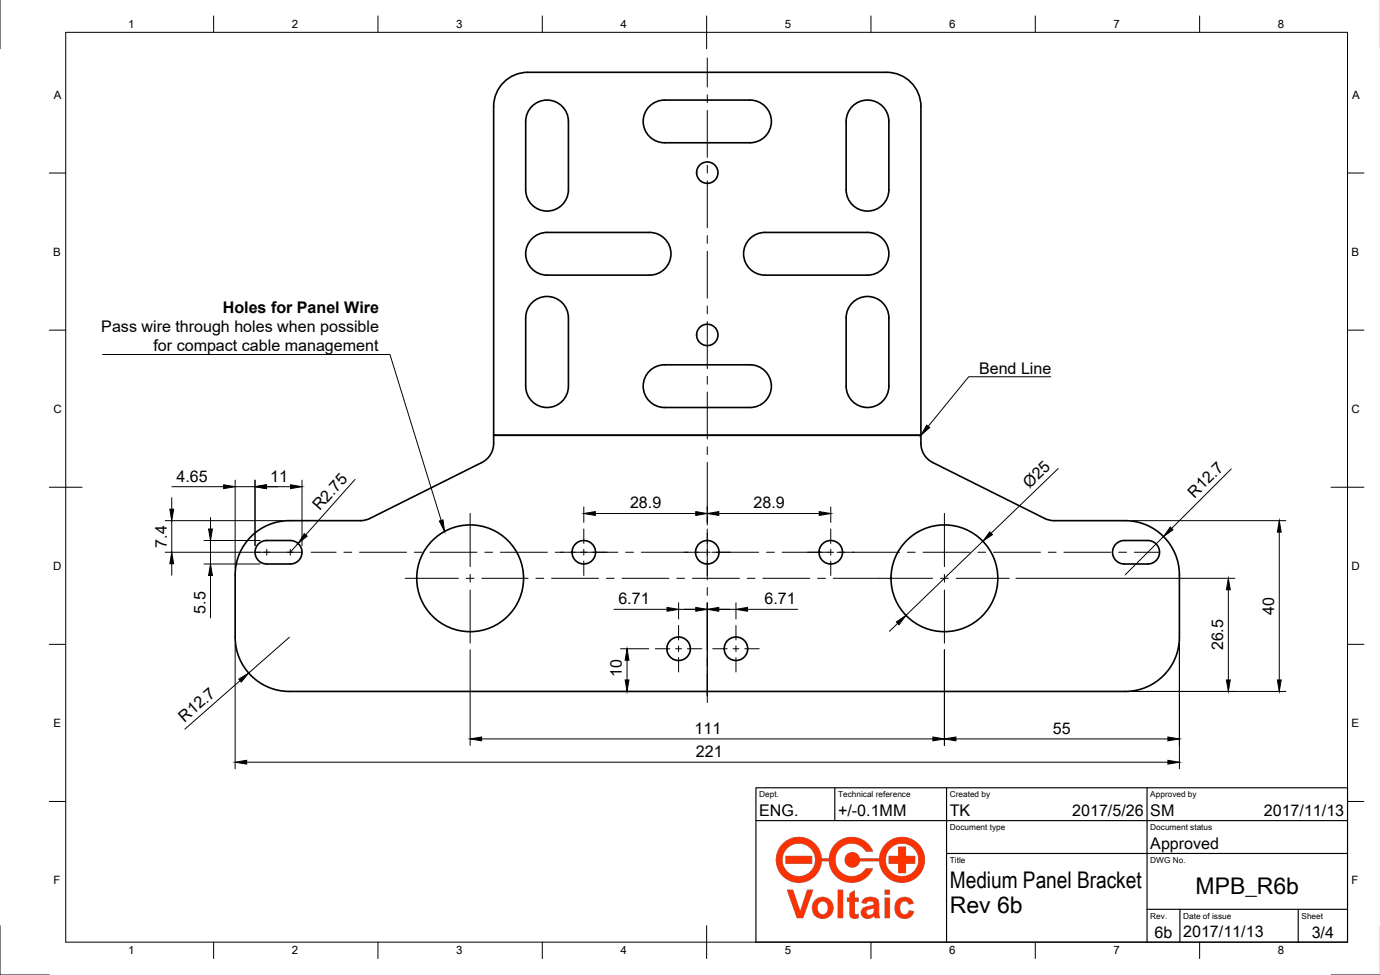
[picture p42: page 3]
Bend Line

Holes for Panel Wire

Pass wire through holes when possible

for compact cable management

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

Document type | Document status Approved

Title Medium Panel Bracket | DWG No. MPB_R6b

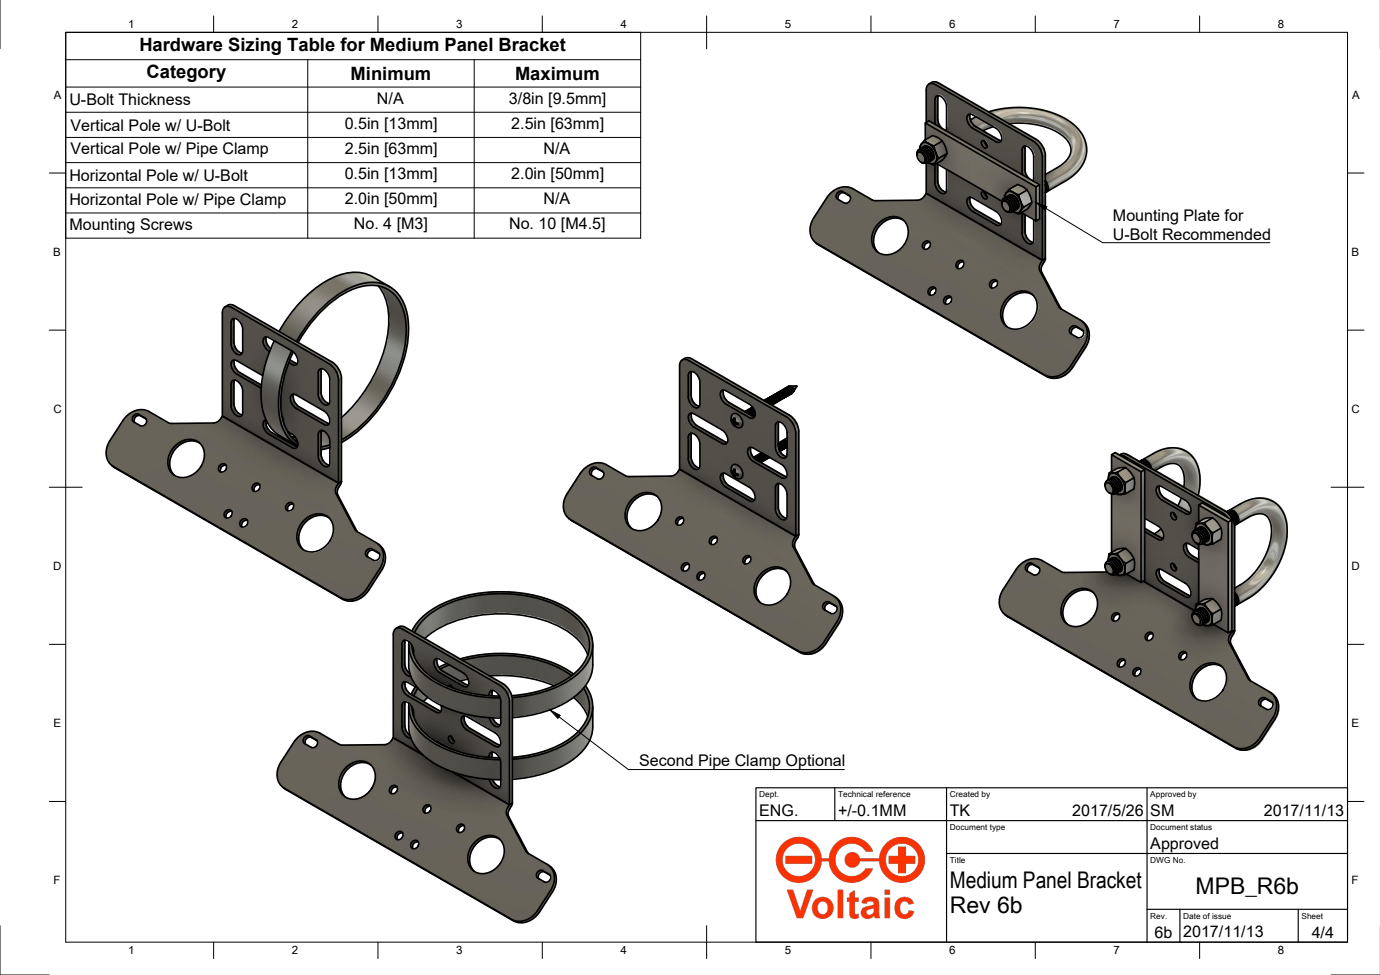
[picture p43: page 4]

Hardware Sizing Table for Medium Panel Bracket
Category | Minimum | Maximum

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

Mounting Plate for
U-Bolt Recommended

Second Pipe Clamp Optional

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

Document type | Document status Approved

Title Medium Panel Bracket | DWG No. MPB_R6b

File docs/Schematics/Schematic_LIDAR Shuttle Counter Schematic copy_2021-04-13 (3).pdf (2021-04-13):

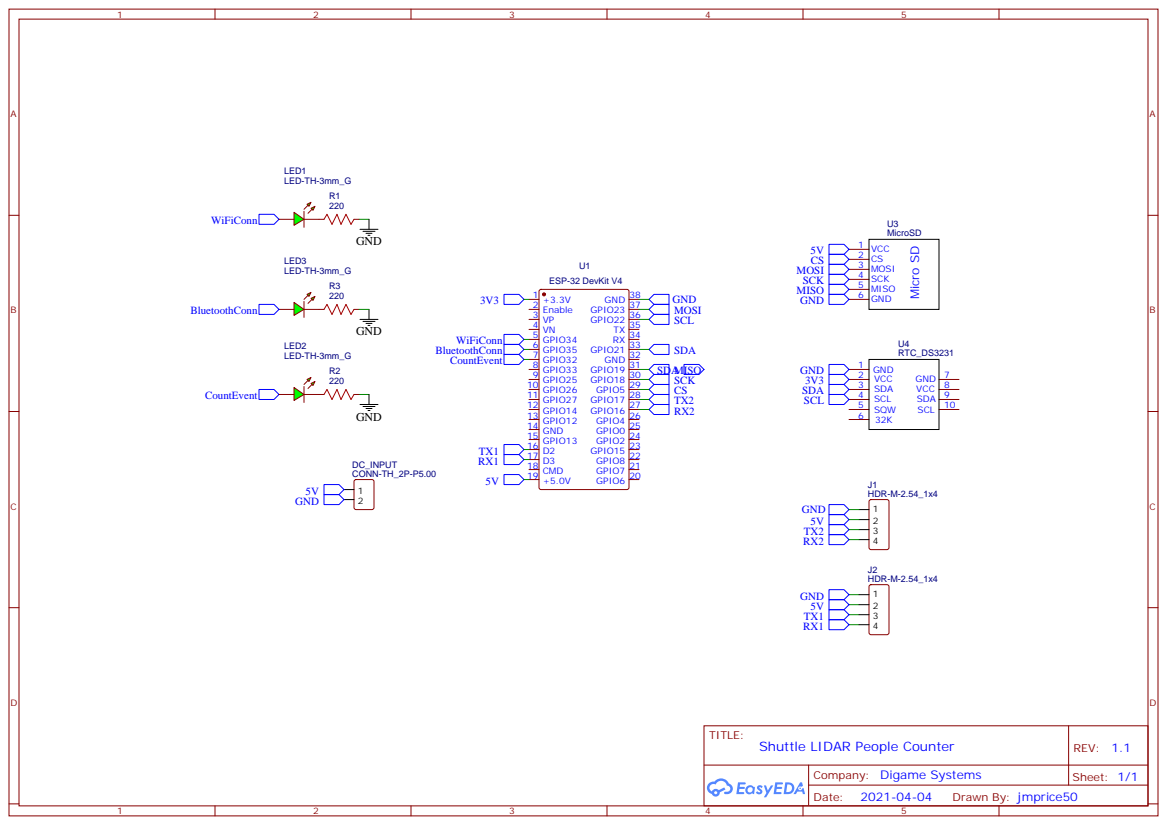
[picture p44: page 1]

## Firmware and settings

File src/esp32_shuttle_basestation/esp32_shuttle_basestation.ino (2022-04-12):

/*
    Shuttle_Basestation
    
    An application to log data from directional people-counters on shuttle 
    buses. Reports rider In/Out behavior for the entire shuttle route to the
    Parkdata System when a shuttle returns within range of a specific WiFi SSID
    desigated as the "reportLocation".

    As the bus travels its route, WiFi SSIDs are used to track location. If 
    events are logged at an unknown location a pseudo location starting with 'UN' 
    is created.
    
    Written for the ESP32 WROOM Dev board V4 
    (Incl. WiFi, Bluetooth, and stacks of I/O.)
    
    https://docs.espressif.com/projects/esp-idf/en/latest/esp32c3/hw-reference/esp32c3/user-guide-devkitc-02.html

    Copyright 2021, Digame Systems. All rights reserved.
*/
#define SW_VERSION "1.0.0"
#define INBOUND  0  // The direction of counter events
#define OUTBOUND 1
#define NUM_COUNTERS 2
#define SHUTTLE 0 // Friendlier names for indicies
#define TRAILER 1

#include <digameDebug.h>      // Serial debugging defines. 
#include <digameFile.h>       // SPIFFS file Handling
#include <digameTime.h>       // Time functions for RTC, NTP, etc. 
#include <digameNetwork_v2.h> // For connections, MAC Address and reporting.
#include <digameDisplay.h>    // eInk Display support.

#include "BluetoothSerial.h"  // Virtual UART support for Bluetooth Classic - part of Arduino-ESP32 from Espressif 
#include <WiFi.h>           
#include <ArduinoJson.h>      // Nifty JSON library
#include <CircularBuffer.h>   // Adafruit library for handling circular buffers of data. 


// For Over the Air (OTA) updates... 
#include <AsyncTCP.h>
#include <ESPAsyncWebServer.h>
#include <AsyncElegantOTA.h>

bool useOTA = false; 

//****************************************************************************************
//****************************************************************************************                        
// Create AsyncWebServer object on port 80
AsyncWebServer server(80);

const int samples = 100;

CircularBuffer<String *, samples> shuttleStops; // A buffer containing pointers to JSON messages to be 
                                                // sent to the LoRa basestation or server.

NetworkConfig networkConfig; // See digameNetwork_v2.h for structure definition.

BluetoothSerial btUART1; // Create a BlueTooth Serial port to talk to the counter
BluetoothSerial btUART2; // Create a BlueTooth Serial port to talk to the counter

struct ShuttleStop { 
  String location       = "UNK";  
  String startTime      = "00:00:00"; // When we got to this location
  String endTime        = "00:00:00"; // When we last saw an event while here
  String counterMACAddresses[NUM_COUNTERS]    = {"",""};  // TODO: Consider moving into the "BaseStation"
  unsigned int counterEvents[NUM_COUNTERS][2] = {{0, 0},  // Counter 0, in/out count
                                                 {0, 0}}; // Counter 1, in/out count                              
};

ShuttleStop currentShuttleStop;

String routeName   = "Route Name";
String shuttleName = "Shuttle Name";

String reportingLocation         = "ReportingSSID";
String reportingLocationPassword = "ReportingPW";

String knownLocations[] = {"Stop 1", 
                           "Stop 2", 
                           "Stop 3",
                           "Stop 4",
                           "Stop 5",
                           "Stop 6",
                           "Stop 7",
                           "Stop 8",
                           "Stop 9",
                           "Stop 10",
                           "Stop 11"};

String counterNames[]     = {"ShuttleCounter_1234", "ShuttleCounter_2345"}; 

uint8_t counter1Address[] = {0xAC,0x0B,0xFB,0x25,0xC6,0x12};
uint8_t counter2Address[] = {0xE8,0x68,0xE7,0x30,0xAA,0x0E};

String currentLocation  = "UNK"; 
String previousLocation = "UNK";

String titleToDisplay = "";
String textToDisplay1 = "";
String textToDisplay2 = "";

int    CTR_RESET = 32;     // Counter Reset Input

// Multi-Tasking
SemaphoreHandle_t mutex_v;     // Mutex used to protect variables across RTOS tasks. 
TaskHandle_t eInkManagerTask;  // A task to update the eInk display.

// Utility Function: Number of items in an array
#define NUMITEMS(arg) ((unsigned int) (sizeof (arg) / sizeof (arg [0])))

// WiFi
String scanForKnownLocations(String knownLocations[], int arraySize);

// UI
void showSplashScreen();
void showCountDisplay(ShuttleStop &shuttleStop);
void eInkManager(void *parameter); // TASK that runs on Core 0

// Initialization
void configureIO();
void configureDisplay();
void accessPointModeCheck();
void configureRTC();
void configureWiFi();
void configureBluetooth(); 
void configureEinkManagerTask();
void configureOTA();

// Load/Save Defaults
void loadParameters();
void saveParameters();

// Bluetooth Counter Communication
bool   connectToCounter(BluetoothSerial &btUART, String counter);
bool   connectToCounterAddr(BluetoothSerial &btUART, uint8_t counterAddr[]);
String sendReceive(BluetoothSerial &btUART, String stringToSend, int counterID);

// ShuttleStop wants to be a class...
void   pushShuttleStop(ShuttleStop &shuttleStop);
void   resetShuttleStop(ShuttleStop &shuttleStop);
void   updateShuttleStop(ShuttleStop &shuttleStop, String jsonMessage, int counterNumber);
String getShuttleStopJSON(ShuttleStop &shuttleStop);
void   processLocationChange(ShuttleStop &currentShuttleStop);


//****************************************************************************************
// SETUP - Device initialization                                   
//****************************************************************************************
void setup(){
  
  Serial.begin(115200);   // Intialize terminal serial port
  delay(1000);            // Give port time to initalize

  mutex_v = xSemaphoreCreateMutex(); // The mutex we will use to protect variables 
                                     // across tasks

  configureIO();

  //useOTA = ( digitalRead(CTR_RESET) == LOW ); // Button low at boot = AP mode

  //useOTA = true; //DEBUG
  //DEBUG_PRINT("USE OTA: ");
  DEBUG_PRINTLN(useOTA);
  
  loadParameters();
  showSplashScreen();
  
  configureDisplay();
  accessPointModeCheck();
  
  configureEinkManagerTask();
  
  
  
  configureRTC();
  configureWiFi();

  if (useOTA){
    configureOTA();
  } else {
    configureBluetooth();
    resetShuttleStop(currentShuttleStop);
    
    // Setup our counter. 
    sendReceive(btUART1, "-",0); // Turn off the menu system
    sendReceive(btUART1, "g",0); // Get a value
    sendReceive(btUART1, "c",0); // Clear the counter    
  }
  
  
  DEBUG_PRINTLN();
  DEBUG_PRINTLN("RUNNING!");
  DEBUG_PRINT("mainLoop Running on Core #: ");
  DEBUG_PRINTLN(xPortGetCoreID());
  DEBUG_PRINTLN();
}


//****************************************************************************************
// MAIN LOOP                                   
//****************************************************************************************
unsigned int t1=-600000,t2=t1;
unsigned int t3=0,t4=t3;
unsigned int networkScanInterval = 15000;
unsigned int counterPollingInterval = 1000;

void loop(){

  t2=millis();

  if (useOTA){

    
  } else {
    
    // Scan for known SSIDs.
    if ((t2-t1) > networkScanInterval){
      currentLocation  = scanForKnownLocations(knownLocations, NUMITEMS(knownLocations));
      DEBUG_PRINTLN("Previous Location: " + previousLocation + " Current Location: " + currentLocation);
      t1=millis(); 
    }
  
    if (currentLocation != previousLocation){ // We've moved
      DEBUG_PRINTLN("New Location!");
      
      String counterStats = sendReceive(btUART1, "g",0); // Get the current count
      if (counterStats !="") updateShuttleStop(currentShuttleStop, counterStats, 0);
      
      processLocationChange(currentShuttleStop);
      
      // Get ready to take data here, at the new location
      counterStats = sendReceive(btUART1, "c",0); // Clear the counter
      resetShuttleStop(currentShuttleStop);
  
      //titleToDisplay = "LOCATION";
      //textToDisplay1 = "\n " + currentLocation + "\n\n Awaiting Counts...";
    }
   
    // Poll the counters.
    t4 = millis();
    if ((t4-t3) > counterPollingInterval){
      String counterStats = sendReceive(btUART1, "g", 0);
      if (counterStats !="") updateShuttleStop(currentShuttleStop, counterStats, 0);
      t3 = millis();   
    }
        
  }  
  delay(20);
}


//****************************************************************************************
bool countsChanged (ShuttleStop shuttleStop) // Have the shuttleStop's counters changed
                                             // since we last asked?
//****************************************************************************************
{
  static int lastInCount = 0;
  static int lastOutCount = 0;
  bool retValue = false;
  
  if ( (lastInCount  != shuttleStop.counterEvents[SHUTTLE][INBOUND]) ||
       (lastOutCount != shuttleStop.counterEvents[SHUTTLE][OUTBOUND]) ) 
  {   
    retValue = true;
    lastInCount  = shuttleStop.counterEvents[SHUTTLE][INBOUND];
    lastOutCount = shuttleStop.counterEvents[SHUTTLE][OUTBOUND];   
  }

  //DEBUG_PRINTLN("countsChanged says: " + String(retValue));
  return retValue; 
  
}

  bool displayTextChanged(String displayText){
  static String oldText = "";
  bool retVal = false;
  
  if (displayText != oldText){
    retVal = true;
    oldText = displayText;  
  }  

  return retVal;  
}


//****************************************************************************************
// An "Old-School" UI Element from my DOS days! 
//****************************************************************************************
String rotateSpinner(){
  static String spinner = "|";
  //OLD SCHOOL! :)
  if (spinner == "|") {
    spinner = "/";
  } else if (spinner == "/") {
    spinner = "-";
  } else if (spinner == "-") {
    spinner = "\\";
  } else { 
    spinner = "|";
  }
  return spinner;
}

//****************************************************************************************
// A TASK that runs on Core0. Updates the eInk display with the currentShuttleStop data
// if it has changed.
//****************************************************************************************
void eInkManager(void *parameter){
  const unsigned int displayUpdateInterval = 500;
  
  for(;;){   
    
    vTaskDelay(displayUpdateInterval / portTICK_PERIOD_MS);
  
    // Check if we need an update to the display to show new counts... 
    if (countsChanged(currentShuttleStop)) {
        showCountDisplay(currentShuttleStop);
    } else if (displayTextChanged(textToDisplay1)) {
      displayTextScreen(titleToDisplay,textToDisplay1,textToDisplay2);  
    } 

    showPartialXY(rotateSpinner(),230,100);
    
  }
}
    


//****************************************************************************************
void deliverRouteReport(){
//****************************************************************************************
  String reportToIssue; 
  bool postSuccessful = false;

  while (shuttleStops.size() > 0){ 
    DEBUG_PRINT("Buffer Size: ");
    DEBUG_PRINTLN(shuttleStops.size());

    reportToIssue = routeReportPrefix(); 

    // FAILURE MODE: 
    // This is a nifty opportunity to get hung up. If we pull into the reporting 
    // location and someone pulls the plug on the router, we'll hang here forever looking
    // for it...

    titleToDisplay = "Reporting Hub";
    textToDisplay1 = "Sending Report...";
    textToDisplay2 = "";
    
    if (WiFi.status() != WL_CONNECTED){  
      while (!(WiFi.status() == WL_CONNECTED)){enableWiFi(networkConfig);}
    }

    
    String activeShuttleStop = String(shuttleStops.first()->c_str()); // Read from the buffer without removing the data from it.
    DEBUG_PRINTLN(activeShuttleStop);
    reportToIssue += activeShuttleStop;
    //if (shuttleStops.size>1) reportToIssue += ","
    reportToIssue += "]}";

    DEBUG_PRINTLN(reportToIssue);
  
    postSuccessful = postJSON(reportToIssue, networkConfig);

    if (postSuccessful) {
      String  * entry = shuttleStops.shift();
      delete entry;
      DEBUG_PRINTLN("Success!");
      DEBUG_PRINTLN();
    }

  }

  titleToDisplay = "Reporting Hub";
  textToDisplay1 = "Sending Complete.";
  textToDisplay2 = "";
  delay(2000); // Give folks a sec to read the update.
 
   
}

//****************************************************************************************
void processLocationChange(ShuttleStop &currentShuttleStop)
//****************************************************************************************
{
  // Log what happened at the last location
  if (currentShuttleStop.endTime != "00:00:00"){ // Append report structure if events are present. 
    pushShuttleStop(currentShuttleStop);
  }

  
  if (currentLocation == reportingLocation){
    DEBUG_PRINTLN("We have arrived at the reportingLocation!"); 
    deliverRouteReport();
  } else if (previousLocation == reportingLocation){
    DEBUG_PRINTLN("We have left the reportingLocation!");
  } else {
    DEBUG_PRINTLN("We have changed shuttle stops!");
  }
  
  previousLocation = currentLocation;
}


// IO Routines

//****************************************************************************************
void loadParameters(){
//****************************************************************************************
  StaticJsonDocument<2048> doc;  
  //DEBUG_PRINTLN("LOADING DEFAULT PARAMETERS...");
  
  if(!SPIFFS.begin()){
    DEBUG_PRINTLN("    File System Mount Failed");
    while (1) {} // Halt and spin...
  
  } else {
    //DEBUG_PRINTLN("    SPIFFS up!");
    String temp;

    //DEBUG_PRINTLN("    Reading file...");
    temp = readFile(SPIFFS, "/config.txt");
    DEBUG_PRINTLN(temp);
    // Deserialize the JSON document
    DeserializationError error = deserializeJson(doc, temp);
    if (error)
    {
      Serial.println(F("    Failed to parse file, using default configuration"));
      return;
    } 
    //DEBUG_PRINTLN((const char *)doc["shuttleName"]);  
    shuttleName               = (const char *)doc["shuttleName"];
    routeName                 = (const char *)doc["routeName"];
    reportingLocation         = (const char *)doc["reportingLocation"];
    reportingLocationPassword = (const char *)doc["reportingLocationPassword"];

    
    networkConfig.ssid      = reportingLocation;
    networkConfig.password  = reportingLocationPassword;
    networkConfig.serverURL = "http://199.21.201.53/trailwaze/zion/lidar_shuttle_import.php";
    
    //DEBUG_PRINTLN(doc["knownLocations"].size());
    
    for (int i=0; i<doc["knownLocations"].size(); i++){
      knownLocations[i] = String((const char *)doc["knownLocations"][i]);
      //DEBUG_PRINTLN(knownLocations[i]);
    }
    
    for (int i=0; i<doc["counterNames"].size(); i++){
      counterNames[i] = String((const char *)doc["counterNames"][i]);
      //DEBUG_PRINTLN(counterNames[i]);
    }
  }    
}

//****************************************************************************************
// Saves the configuration to a file
//****************************************************************************************
void saveParameters()
{
  if (SPIFFS.begin()){
    DEBUG_PRINTLN("SPIFFS up!");  
  } else { 
    DEBUG_PRINTLN("Trouble mounting SPIFFS!");
    return;
  }

  const char *filename = "/config.txt";
  SPIFFS.remove(filename);

  File file = SPIFFS.open(filename, FILE_WRITE);
  if (!file)
  {
    Serial.println(F("    Failed to create file!"));
    return;
  }

  // Allocate a temporary JsonDocument
  // Don't forget to change the capacity to match your requirements.
  // Use https://arduinojson.org/assistant to compute the capacity.
  StaticJsonDocument<2048> doc;

  // Copy values from the Config struct to the JsonDocument
  doc["routeName"] = routeName;
  doc["shuttleName"] = shuttleName;
  doc["reportingLocation"] = reportingLocation;
  doc["reportingLocationPassword"] = reportingLocationPassword;
  doc["counterNames"][0] = counterNames[0];
  doc["counterNames"][1] = counterNames[1];

  
  doc["knownLocations"][0] = knownLocations[0];
  doc["knownLocations"][1] = knownLocations[1];
  doc["knownLocations"][2] = knownLocations[2];
  doc["knownLocations"][3] = knownLocations[3];
  doc["knownLocations"][4] = knownLocations[4];
  doc["knownLocations"][5] = knownLocations[5];
  doc["knownLocations"][6] = knownLocations[6];
  doc["knownLocations"][7] = knownLocations[7];
  doc["knownLocations"][8] = knownLocations[8];
  doc["knownLocations"][9] = knownLocations[9];
  doc["knownLocations"][10] = knownLocations[10];

  
  DEBUG_PRINTLN("Writing file...");

  if (serializeJson(doc, file) == 0)
  {
    DEBUG_PRINTLN("    Failed to write file!");
  }

  // Close the file
  DEBUG_PRINTLN("Closing file...");

  file.close();
}


//***************************************************************************************
String processor(const String& var)
//***************************************************************************************
{

  if(var == "config.deviceName") return F(shuttleName.c_str()); 
  if(var == "baseStationName") return F(shuttleName.c_str()); 
  if(var == "counterName") return F(counterNames[0].c_str()); 
  if(var == "reportingLocation") return F(reportingLocation.c_str()); 
  if(var == "password") return F(reportingLocationPassword.c_str()); 
  if(var == "stop1") return F(knownLocations[0].c_str()); 
  if(var == "stop2") return F(knownLocations[1].c_str()); 
  if(var == "stop3") return F(knownLocations[2].c_str()); 
  if(var == "stop4") return F(knownLocations[3].c_str()); 
  if(var == "stop5") return F(knownLocations[4].c_str()); 
  if(var == "stop6") return F(knownLocations[5].c_str()); 
  if(var == "stop7") return F(knownLocations[6].c_str()); 
  if(var == "stop8") return F(knownLocations[7].c_str()); 
  if(var == "stop9") return F(knownLocations[8].c_str()); 
  if(var == "stop10") return F(knownLocations[9].c_str()); 
  
  return "";
}


//*******************************************************************************************************
void redirectHome(AsyncWebServerRequest* request){
    
    saveParameters(); // Save any changes before redirecting home
    
    String RedirectUrl = "http://";
    if (ON_STA_FILTER(request)) {
      RedirectUrl += WiFi.localIP().toString();
    } else {
      RedirectUrl += WiFi.softAPIP().toString();
    }
    RedirectUrl += "/";
    request->redirect(RedirectUrl);
}

//*******************************************************************************************************
void processQueryParam(AsyncWebServerRequest *request, String qParam, String *targetParam){
    //debugUART.println(qParam);
    if(request->hasParam(qParam)){
      //debugUART.println("found");
      AsyncWebParameter* p = request->getParam(qParam);

      debugUART.print(p->value());
      debugUART.print(" ");
      debugUART.println(String(p->value()).length());


      if (String(p->value()).length() == 0) {
        //debugUART.println("*******BLANK ENTRY!*******");
        //debgugUART.println("...ignoring...");
      
      } else{
        *targetParam = String(p->value().c_str());
        targetParam->replace("%","_"); // Replace the template character. 
                                     // 'Might cause problems w/ some Passwords...
                                     // TODO: Think on this. Make '%' illegal in PW? 
      }
    }
}

//****************************************************************************************
void configureOTA(){
//****************************************************************************************

  DEBUG_PRINTLN("  Stand-Alone Mode. Setting AP (Access Point)…");  
  WiFi.mode(WIFI_AP);
  
  String netName = "BaseStation_" + getShortMACAddress();
  const char* ssid = netName.c_str();
  WiFi.softAP(ssid);
  
  IPAddress IP = WiFi.softAPIP();
  DEBUG_PRINT("    AP IP address: ");
  DEBUG_PRINTLN(IP);   

  titleToDisplay = "Access Point";
  textToDisplay1 = "BaseStation_" + getShortMACAddress();
  textToDisplay2 = WiFi.softAPIP().toString();;
 
  //delay(3000);  
  
  server.on("/", HTTP_GET, [](AsyncWebServerRequest *request){
    DEBUG_PRINTLN(" Web Request Received.");
    
    if(!request->authenticate("admin", "admin"))
      return request->requestAuthentication();
      
    request->send(SPIFFS, "/index.html", String(), false, processor);
  
  });

  server.on("/parameters",HTTP_GET, [](AsyncWebServerRequest *request){
    processQueryParam(request, "baseName", &shuttleName);
    processQueryParam(request, "counterName", &counterNames[0]);

    processQueryParam(request, "reptLocation", &reportingLocation);
    processQueryParam(request, "password", &reportingLocationPassword);

    for (int i = 0; i<9; i++){
      processQueryParam(request, "stop" + String(i+1), &knownLocations[i]);
    }
     
    redirectHome(request);
    
  });

  server.serveStatic("/", SPIFFS, "/"); // sets the base path for the web server
  AsyncElegantOTA.begin(&server);   
  server.begin();
}


// UI Routines

//****************************************************************************************
// Program Splash / copyright.
//****************************************************************************************
void showSplashScreen(){
  DEBUG_PRINTLN("*****************************************************");
  DEBUG_PRINTLN("ParkData Shuttle Counter Base Station");
  DEBUG_PRINTLN("Version 1.0");
  DEBUG_PRINT("Device Name: ");
  DEBUG_PRINTLN(shuttleName);
  DEBUG_PRINTLN("Copyright 2022, Digame Systems. All rights reserved.");
  DEBUG_PRINTLN();
  DEBUG_PRINTLN("               Hit <ENTER> for Menu"); 
  DEBUG_PRINTLN("*****************************************************");  
  DEBUG_PRINTLN();
  DEBUG_PRINTLN("HARDWARE INITIALIZATION");
  DEBUG_PRINTLN();  
}
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

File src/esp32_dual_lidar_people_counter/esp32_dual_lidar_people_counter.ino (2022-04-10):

/*
    Heimdall -- "Heimdall sees all!" 

    This program uses a pair of TFMini-plus LIDARs to count people boarding /
    unboarding shuttle buses. 
    
    The two sensors are used in combination to determine direction of travel and 
    thereby if a person is boarding or exiting.
    
    Data is reported in JSON format via Bluetooth classic. 
    
    LIDAR Sensor:
    http://en.benewake.com/product/detail/5c345cd0e5b3a844c472329b.html
    (See manual in /docs folder.)

    Written for the ESP32 WROOM Dev board V4 (Incl. WiFi, Bluetooth, and stacks of I/O.)
    https://docs.espressif.com/projects/esp-idf/en/latest/esp32c3/hw-reference/esp32c3/user-guide-devkitc-02.html

    Copyright 2021, Digame Systems. All rights reserved.

    Testing the Sensor: 
    https://youtu.be/LPxUawpHUEk
    https://youtu.be/7mM1T-jgChU
    https://youtu.be/dQw4w9WgXcQ

*/

#define HARDWARE_PRESENT true // Flag so we can debug the code without LIDAR sensors.

//****************************************************************************************
//****************************************************************************************

#define tfMiniUART_1 Serial1
#define tfMiniUART_2 Serial2


//****************************************************************************************
//****************************************************************************************
#include <digameDebug.h>     // Serial debugging defines. 
#include <digameFile.h>      // Read/Write Text files.
#include <digameNetwork.h>   // For MAC address functions

#include "BluetoothSerial.h" // Part of the ESP32 board package. 
                             // By Evandro Copercini - 2018

#include <TFMPlus.h>         // Include TFMini Plus LIDAR Library v1.4.0
                             // https://github.com/budryerson/TFMini-Plus

#include <SPIFFS.h>          // FLASH file system support.


// For Over the Air (OTA) updates... 
#include <AsyncTCP.h>
#include <ESPAsyncWebServer.h>
#include <AsyncElegantOTA.h>

bool useOTA = true; 

//****************************************************************************************
//****************************************************************************************                        
// Create AsyncWebServer object on port 80
AsyncWebServer server(80);

TFMPlus tfmP_1;         // Create a TFMini Plus object for sensor 1
TFMPlus tfmP_2;         // Create a TFMini Plus object for sensor 2

BluetoothSerial btUART; // Create a BlueTooth Serial Port Object


//****************************************************************************************
//****************************************************************************************
// Smoothing the LIDAR signals to get rid of noise and introduce a bit of a decay time. 
float smoothed_LIDAR_1 = 0.0;
float smoothed_LIDAR_2 = 0.0;

// We're tracking the visibility of the target on both sensors. Valid events go from only 
// visible on one sensor to being visible on both. Direction is determined by which sensor
// sees the target first. 
int previousState = 0; 
int state         = 0; 

#define OUTBOUND  1
#define INBOUND   2
#define BOTH      3

unsigned int inCount  = 0;
unsigned int outCount = 0;

String deviceName        = "Shuttle 6";
float  distanceThreshold = 160;
float  smoothingFactor   = 0.95;

bool streamingRawData = false; 
bool menuActive = false;

bool clearDataFlag = false; 

String jsonPayload;
String jsonPrefix;  


//****************************************************************************************
// Overloading print and println to send messages to both serial and bluetooth connections
// There must be a better way to do this with a #define 
//****************************************************************************************
void dualPrintln(String s="");
void dualPrint(String s="");
void dualPrintln(float f);
void dualPrint(float f);
void dualPrintln(int i);
void dualPrint(int i);

void loadDefaults();

void showSplashScreen();
void showMenu();

String getUserInput();
void   scanForUserInput();

void  configureWiFi();
void  configureBluetooth();
void  configureLIDARs();

void  configureOTA();

void initLIDAR(TFMPlus &tfmP, int port=1);
int  processLIDAR(TFMPlus &tfmP, float &smoothed, int offset);


//****************************************************************************************                            
void setup() // - Device initialization
//****************************************************************************************
{
  Serial.begin(115200);   // Intialize terminal serial port
  delay(1000);            // Give port time to initalize
  
  loadDefaults();
  
  DEBUG_PRINTLN("INITIALIZING HARDWARE...");
  
  configureWiFi();
  configureBluetooth();
  configureLIDARs();

  if (useOTA) {
    configureOTA();  
  }

  // The first part of all of our JSON messages
  jsonPrefix = "{\"deviceName\":\"" + deviceName + "\",\"deviceMAC\":\"" + WiFi.macAddress();

  DEBUG_PRINTLN();
  DEBUG_PRINTLN("RUNNING!");

     
}


//****************************************************************************************
void loop()  // Main 
//****************************************************************************************
{ 
  scanForUserInput();
  
  if (clearDataFlag){
    inCount = 0; 
    outCount = 0;
    clearDataFlag = false;    
  }

  // Run a little state machine based on the visibility of a target
  // on the two LIDAR sensors

  int visible = 0;
  state = 0;

  // Target visible on sensor 1?
  visible = processLIDAR(tfmP_1, smoothed_LIDAR_1, 100); 
  
  if (visible>=0){
    
    state = state + visible;

    // Target visible on sensor 2?
    visible = processLIDAR(tfmP_2, smoothed_LIDAR_2, 110);
    state = state + visible * 2;

    if (streamingRawData) dualPrintln(distanceThreshold);

    if (state == BOTH){ // Visible on both Sensors
      jsonPayload = jsonPrefix; 
    
      if ((previousState == INBOUND)){ // INBOUND event
        inCount += 1;
        jsonPayload = jsonPayload + "\",\"eventType\":\"inbound" +
                       "\",\"count\":\"" + inCount + "\"" +
                       "}";
  
        if ((!streamingRawData)&&(menuActive)) dualPrintln(jsonPayload); 
      }
    
      if ((previousState == OUTBOUND)){ // OUTBOUND event
        outCount += 1;
        jsonPayload = jsonPayload + "\",\"eventType\":\"outbound" +
                      "\",\"count\":\"" + outCount + "\"" +
                      "}";
  
        if ((!streamingRawData)&&(menuActive)) dualPrintln(jsonPayload);
      }
      
    }
    previousState = state;
  }
}


//****************************************************************************************
void configureWiFi(){
//****************************************************************************************
  DEBUG_PRINTLN(" WiFi...");

}
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

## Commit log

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2021-04-07 updated project to ESP32_people_counter. Started addin g in SD card support. Self calibration for baseline.
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2021-04-24 added polycase cad files
    [LP-61BFMB.dwg, LP-61BFMB.dxf, LP-61C-R.dwg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]
2021-04-25 adding docs for TFMini-Plus Certs / CAD
    [TFmini Plus 3D structure model.igs]
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2021-04-27 A couple of tweaks to the shuttle counter code. Added Certification Docs for the LIDAR sensor. Updated Readme for the ESP32 to include link to a page describing pinouts.
2021-04-28 Added a little simulation of what rain might be doing to the LIDAR siganals.
    [Rain Simulation.xlsx]
2021-04-28 New simulation using cross correlation. Added TF-LUNA docs
    [Rain Simulation (cross correlation).xlsx, Rain Simulation.xlsx]
2021-05-01 developing LIDAR correlation test code
    [Cross Correlation Expt.xlsx, Rain Simulation (cross correlation).xlsx]
2021-05-01 *** Restructuring the Docs Directory ***
    [Cross Correlation Expt.xlsx, Rain Simulation (cross correlation).xlsx, TFmini Plus 3D structure model.igs]
2021-05-04 Added polycase files for several enclosures, added e-Ink display example, tweaks to correlation test program, updated vehicle counter program for hardware detection and algorithm selection from file.
    [LP-61BFMB.dwg, LP-61BFMB.dxf, LP-61C-R.dwg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]
2021-05-06 Blender models for TFMini-Plus and E-Ink Display. Vendor Docs
    [1_54inch_display.blend, WC-23C+08.DWG, WC-23F+1508.DWG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]
2021-05-08 breaking out different ePaper displays in docs folder
    [1_54inch_display.blend, Micro_SD_Breakout.blend, WC-23F.STEP]
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2021-05-23 Lots of additions: Multi-threading in vehicle counter code, support for partial updates in Adafruit eInk display, conditional compiles for different hardware and images / docs.
2021-06-01 Added 3d Cad of solar panel and battery. Updates to Heimdall for power management. New LoRa code for testing.
    [solar panel and battery.blend]
2021-06-11 Update esp32_ttminiplus_sd_ds3231.ino
    Move closing bracket inside the if statement for rawSignal field.
2021-06-11 Update esp32_ttminiplus_sd_ds3231.ino
    Correction for last commit, need to have separate line for closing curly brace so it's always there.
    [esp32_ttminiplus_sd_ds3231.ino]
2021-06-22 broke out a speparate project for the lora vehicle counter. Updates to TX and RX LoRa examples to perform ack handshaking
    [digameDisplay.h]
2021-07-01 Working on LoRa based counter and base station. Added example for ESP32 based web server we might use for configuration
2021-07-07 added esp32 web server to base station. Expanded config to include sensor names and MAC addresses.
2021-07-08 updated base station to host a web interface in ap mode when reset button is held down at boot. Same for counter. Branched to _v2 project since I removed much of the networking from the sensor code.
2021-07-13 fixed a bug in _V2 where LIDAR parameters were not being properly saved. Fixed year format in digameTime.h to use full YYYY format.
    [digameJSONConfig.h, esp32_lora_basestation.ino, esp32_tfminiplus_sd_ds3231_eink_lora_v2.ino]
2021-07-15 changed time format from sensors over LoRa back to short year format. Base station now adds the 20 to the date.\
    [esp32_lora_basestation.ino, esp32_tfminiplus_sd_ds3231_eink_lora_v2.ino]
2021-07-16 Modified JSONconfig to test for file and if not found create it from defaults. Changed LIDAR to report 12M when return signal is too low to detect.
    [digameJSONConfig.h, esp32_lora_basestation.ino, esp32_tfminiplus_sd_ds3231_eink_lora_v2.ino]
2021-07-16 Changes to base station setup. Test for uninitialized unit and drop into AP mode if unconfigured. -- Tweaks to power mgt routines.
2021-07-18 Added some photos of the new module / battery pack and did some code cleanup in prep for release.
2021-08-04 Consolidating digame libraries. Updates to digameDisplay to handle new eInk displays (compile time option currently). Fixed RTC bug for un-initialized RTC modules. Added FW Version information to mes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
    [digameDisplay.h, esp32_lora_basestation.ino]
2021-08-11 0.9.5 testing release for updated lora base station and counter code. Multi-Tasking for network / lora and display updates. Changes to http POST in base station to dramatically improve upload speed. 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
2021-08-12 Adding in provisions to switch which ePaper display is used at run time. Added LIDAR parameters to counter code in boot and heartbeat messages so Jared can develop a dashboard of settings.
2021-08-12 added sample params.txt file
    [params.txt]
2021-08-16 Updates to counter and basestation code to share a version header. Working on digameDisplay.h Tweaks to LIDAR algorithm.
2021-08-25 Updates to RTC setter to use Config Struct and digameNetwork.h. Webserver tweaks to reinitialize LoRa params on change. EEPROM support for display type now working. Uninitialized ESP32s will prompt f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
2021-10-06 VERSION 0.9.58: Lots of changes. Added new LIDAR detection scheme that uses a voting algorithm for lane determination. Changes to web intereface to handle special characters. Fixed typos in JSON payl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
    [digameJSONConfig.h, digameLIDAR.h, esp32_lora_basestation.ino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]
2021-10-08 fixed memory leak in utilization of the circular buffer library. String classes were not being propery released, leading to a KaBoom after about 100 counts. (Rookie...)
    [digameDisplay.h, digameJSONConfig.h, digameLIDAR.h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]
2021-10-11 Release 0.9.60 -- Fixed a sneaky memory leak bug in the circular buffer used for handling the queue of JSON messages to be posted to the server.
    [digameDisplay.h, digameJSONConfig.h, digameLIDAR.h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]
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2021-12-09 changes to dual lidar and shuttle base station. Reworked counter to use Bluetooth in parallel with Serial for parameter changing and debugging messages.
    [esp32_dual_lidar_people_counter.ino, esp32_shuttle_basestation.ino]
2021-12-09 added a check for streaming raw data to prevent menu from showing up in the raw data stream. This messed up the parser while streaming.
    [esp32_dual_lidar_people_counter.ino]
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2021-12-10 Updates to routeReport format to the server. Base station now reading parameters from JSON config file. Counter updates for dual output to Bluetooth and Serial.
    [config.txt]
2021-12-12 Moved WiFi handling back to the same core as Bluetooth in the base station. Timing tweaks to Dual Counter.
    [config.txt]
2021-12-12 Dual-Lidar code cleanup. Formatting, Fixed some clumsy variable names. Function prototypes. Moved Setup() and Loop() up in the file for clarity.
    [esp32_dual_lidar_people_counter.ino]
2021-12-17 code cleanup. Naming improvements in Dual LIDAR counter code. Tweaks to LIDAR libraries and power management to improve power consumption. Putting LoRa counters into sleep mode for the the LoRa modul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
2021-12-20 fixed a couple of typos in the comments
    [esp32_dual_lidar_people_counter.ino]
2021-12-22 dual counter support for the shuttle base station. upgated the counters to support synchronous operation
    [config.txt]
2021-12-27 Web Page for OTA for dual lidar counter
    [config.txt]
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2021-12-31 added current shuttle stop as a parameter to process location change rather than using the global variable
2021-12-31 refactor eInk manager Task to use a call to countsChanged(currentShuttleStop) to determine if refresh needed
2021-12-31 tweaks to config for testing
    [config.txt]
2022-01-02 refactor lidar counter code. create functions for code blocks in setup() and loop(). Cleaned up setup handling of AP mode selection
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2022-01-03 renamed digame_include dir to include
    [params.txt]
2022-01-12 fix JSON format. add closing quote to message
    [esp32_lora_basestation.ino]
2022-01-12 add variable to web page that is updated by javascript to prevent wifi from getting turned off when user is configuring the device.
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2022-04-06 update display routines to avoid flashing refresh and minimize 'ghosting'
    [esp32_shuttle_basestation.ino]
2022-04-10 update default config.txt
    [config.txt]
2022-04-12 Add RTC and Eink Setup routines to baseline fw load
    [config.txt]

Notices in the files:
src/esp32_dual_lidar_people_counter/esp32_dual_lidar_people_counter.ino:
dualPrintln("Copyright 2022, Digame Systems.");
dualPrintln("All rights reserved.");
